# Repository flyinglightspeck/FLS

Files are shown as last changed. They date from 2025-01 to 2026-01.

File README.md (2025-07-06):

# FLS
Prototypes for flying light specks (FLSs).

This repository contains various designs for an FLS organized in directories named v*. Each design includes the 
electronic parts, 3D printable parts, instructions on assembling and configuring the FLS. 

The latest version is v5. Navigate to its directory for instructions, and assets.

# Writing Path for English Letters

### Table: Number of segments for writing paths of letters

| Letter | # Lit | # Dark | # Return | Total |
|---|---|---|---|---|
| A | 3 | 1 | 1 | 5 |
| B | 3 | 0 | 0 | 3 |
| C | 1 | 0 | 1 | 2 |
| D | 2 | 0 | 0 | 2 |
| E | 4 | 1 | 1 | 6 |
| F | 3 | 1 | 1 | 5 |
| G | 3 | 0 | 1 | 4 |
| H | 3 | 2 | 1 | 6 |
| I | 3 | 2 | 1 | 6 |
| J | 2 | 1 | 1 | 4 |
| K | 3 | 1 | 1 | 5 |
| L | 2 | 0 | 1 | 3 |
| M | 4 | 0 | 1 | 5 |
| N | 3 | 0 | 1 | 4 |
| O | 1 | 0 | 0 | 1 |
| P | 2 | 0 | 1 | 3 |
| Q | 2 | 1 | 1 | 4 |
| R | 3 | 1 | 1 | 5 |
| S | 1 | 0 | 1 | 2 |
| T | 2 | 1 | 1 | 4 |
| U | 2 | 0 | 1 | 3 |
| V | 2 | 0 | 1 | 3 |
| W | 4 | 0 | 1 | 5 |
| X | 2 | 1 | 1 | 4 |
| Y | 3 | 1 | 1 | 5 |
| Z | 3 | 0 | 1 | 4 |

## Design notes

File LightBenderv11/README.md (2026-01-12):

# ArduPilot Parameters
Load the ap_lightbender.params file or set the following parameters on the ArduPilot:

ARMING_CHECK 0

BATT_ARM_VOLT 7.5
BATT_CAPACITY 650
BATT_CRT_VOLT 7.2
BATT_LOW_VOLT 7.3

COMPASS_USE Disabled
COMPASS_USE2 Disabled
COMPASS_USE3 Disabled

EK3_MAG_CAL Use external yaw sensor
EK3_SRC1_POSZ GPS
EK3_SRC1_POSXY GPS
EK3_SRC1_VELZ GPS
EK3_SRC1_VELXY GPS
EK3_SRC1_YAW GPS

GPS_DELAY_MS 50
GPS_TYPE MAV

GYRO_FILTER 100

INS_LOG_BAT_MASK 1
INS_LOG_BAT_OPT 5
INS_HNTCH_ENABLE 1
INS_HNTCH_HMNCS 1 (set to 7 for three harmonics for tri-blade props)
INS_HNTCH_MODE 3 (ESC Telemetry)
INS_HNTCH_FREQ 400 (average hover RPM / 60)
INS_HNTCH_BW 100 (INS_HNTCH_FREQ / 4)
INS_HNTCH_REF 1
INS_HNTCH_OPTS 6 (Multi-source, Update at loop rate)
INS_HNTCH_FREQ 425 (average hover RPM / 60)
INS_HNTCH_BW 40 (at most INS_HNTCH_FREQ / 4)
INS_HNTCH_OPTS# ArduPilot Parameters
Load the ap_lightbender.params file or set the following parameters on the ArduPilot:

ARMING_CHECK 0

BATT_ARM_VOLT 7.5
BATT_CAPACITY 650
BATT_CRT_VOLT 7.2
BATT_LOW_VOLT 7.3

COMPASS_USE Disabled
COMPASS_USE2 Disabled
COMPASS_USE3 Disabled

EK3_MAG_CAL Use external yaw sensor
EK3_SRC1_POSZ GPS
EK3_SRC1_POSXY GPS
EK3_SRC1_VELZ GPS
EK3_SRC1_VELXY GPS
EK3_SRC1_YAW GPS

GPS_DELAY_MS 50
GPS_TYPE MAV

INS_GYRO_FILTER 162
INS_LOG_BAT_MASK 1
INS_LOG_BAT_OPT 5
INS_HNTCH_ENABLE 1
INS_HNTCH_HMNCS 1 (set to 7 for three harmonics for tri-blade props)
INS_HNTCH_MODE 3 (ESC Telemetry)
INS_HNTCH_FREQ 400 (average hover RPM / 60)
INS_HNTCH_BW 100 (INS_HNTCH_FREQ / 4)
INS_HNTCH_REF 1
INS_HNTCH_OPTS 6 (Multi-source, Update at loop rate)
INS_HNTCH_FREQ 375 (around average hover RPM / 60)
INS_HNTCH_BW 40 (start with INS_HNTCH_FREQ / 4 then narrow down)
INS_HNTCH_OPTS 6 (Multi-source, Update at loop rate)

LAND_SPEED 30

LOG_BITMASK 2504447 (Check all except for mission commands, optical flow, camera, raw imu, and video stabilization)

OSD_CELL_COUNT 2

RPM1_TYPE 5 (ESC Telemetry Motors Bitmask)

RPM1_ESC_MASK 15 (Channels 1 - 4)
SERVO_BLH_BDMASK 15 (Channels 1 - 4)
SERVO_BLH_POLES 14 (If using another motor count the number of magnets inside the rotor and put in the correct number)
SERVO_DSHOT_ESC 1 (BLHeli32/Kiss/AM32)

SERIAL1_BAUD 921600

VISO_TYPE MAVLink

LAND_SPEED 30

LOG_BITMASK 2504447 (Check all except for mission commands, optical flow, camera, raw imu, and video stabilization)

OSD_CELL_COUNT 2

RPM1_TYPE 5 (ESC Telemetry Motors Bitmask)

RPM1_ESC_MASK 15 (Channels 1 - 4)
SERVO_BLH_BDMASK 15 (Channels 1 - 4)
SERVO_BLH_POLES 14 (If using another motor count the number of magnets inside the rotor and put in the correct number)
SERVO_DSHOT_ESC 1 (BLHeli32/Kiss/AM32)

SERIAL1_BAUD 921600

VISO_TYPE MAVLink

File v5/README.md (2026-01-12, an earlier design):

# 60mm FLS with MicoAir H743v2 AIO

## V5.3.60

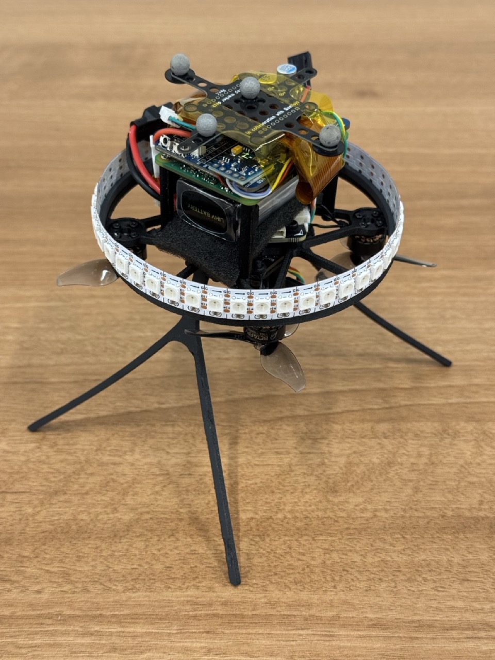
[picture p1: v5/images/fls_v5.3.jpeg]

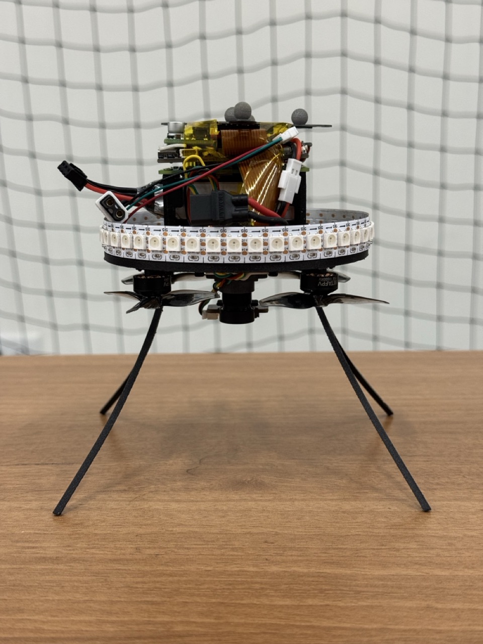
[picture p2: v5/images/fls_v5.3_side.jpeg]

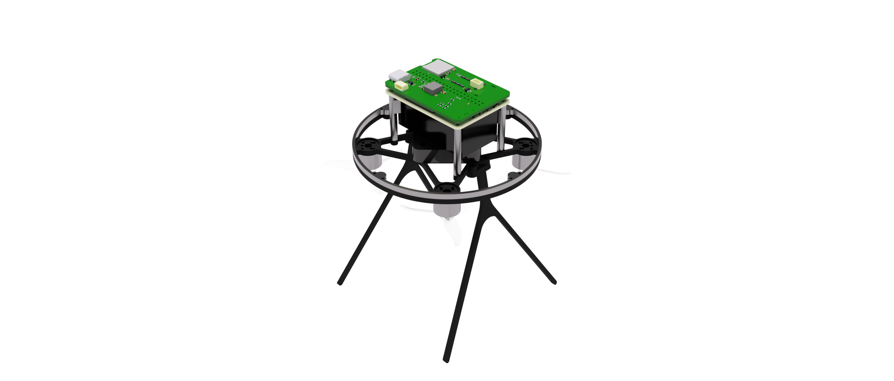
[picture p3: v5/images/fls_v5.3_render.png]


3D model: `v5/3d/FLS_v5.3.60.f3z`.

## Parts

- [MicoAir H743v2 AIO 45A](https://store.micoair.com/product/micoair743v2-aio-45a/)
- [6000KV Motors](https://flywoo.net/products/robo-1303-6000kv-2-4s-fpv-motor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)
- [Raspberry Pi CM5](https://www.raspberrypi.com/products/compute-module-5/?variant=cm5-104032)
- [Raspberry Pi Camera Module 3 Wide NoIR](https://www.pishop.us/product/raspberry-pi-camera-module-3-wide-noir/)
- [Nano Base Board (A) for Raspberry Pi Compute Module 5](https://www.waveshare.com/cm5-nano-a.htm), also
  on [Amazon](https://a.co/d/2dPvVRj)
- [Pololu 5V, 5A Step-Down Voltage Regulator D24V50F5 to power Raspberry Pi](https://www.pololu.com/product/2851)
- [Molex connectors](https://a.co/d/1OW0Edu)
- [2S 650mAh 120C Lipo Battery](https://a.co/d/c1O34hy)
- [Raspberry Pi Camera Module 3 Wide NoIR](https://www.raspberrypi.com/products/camera-module-3/?variant=camera-module-3-noir-wide)
- [Raspberry Pi Camera Module 3 Sensor Cable Extension](https://www.arducam.com/200mm-sensor-extension-cable-for-raspberry-pi-v2-v3-support-working-on-raspberry-pi-and-jetson.html)
- [MicoAir MTF-02 Flow and Range Sensor](https://robofusion.net/products/micoair-optical-flow-lidar-sensor-mtf-02-compatible-with-ardupilot-px4-inav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)
- 2-inch Propellers (Any of the bellow options):
    - [Gemfan D51 Ducted 4-Blade](https://www.getfpv.com/gemfan-d51-ducted-durable-4-blade-51mm-cinewhoop-propeller-set-of-8.html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)
    - [Gemfan Hurricane 2023S 3-Blade](https://www.getfpv.com/propellers/micro-quad-propellers/gemfan-hurricane-2023s-3-blade-propeller-set-of-8.html)
    - [HQProp T2X2X3 3-Blade](https://www.getfpv.com/propellers/micro-quad-propellers/hqprop-t2x2x3-3-blade-propeller-set-of-4.html)

You can also use CM4 instead of CM5 (CM4 is slower than CM5):

- [Raspberry Pi CM4](https://www.raspberrypi.com/products/compute-module-4/?variant=raspberry-pi-cm4104032)
- [Nano Base Board (A) for Raspberry Pi Compute Module 4](https://www.waveshare.com/cm4-nano-a.htm), also
  on [Amazon](https://a.co/d/gfsPdik)

## Assembly

### 3D Print

We used Bambu X1 Carbon printer to print the following parts using Bambu PA6-CF filament. The models are available
in the `3d` directory. All the items you need to print is inside the Bambu project named `print_plates.3mf` open 
this file using Bambu studio and print the plates.

| name | qty |
|---|-----|
| frame_v4 | 1 |
| pi_holder_v2_a | 2 |
| pi_holder_v2_b | 1 |
| pi_holder_v2_b_slit | 1 |
| landing_gear_v3 | 2 |
| cam_holder_l | 1 |
| cam_holder_r | 1 |
| sensor_holder | 1 |

Important Notes:

- Dry the filament before printing for the best result.
- Use smooth PEI / high temp plate.
- Clean the oil, fingerprints, and printing waste from the plate before printing.
- For printing Plate 1 use `0.2mm strength` profile, add 5mm of outer brim, and use `concentric` top and bottom
  surface pattern.
- For Plates 2 and 3 use `0.16mm high quality` profile. Enable 5mm outer brim for Plate 2. Enable manual 
  support for Plate 3.
- After printing completes do not remove the part. Wait util the plate temperature drops to around 40 degrees
  Celsius. Otherwise, the printed part may bend permanently.
- Store the filament in a sealed zip bag after use.

### Installation

1. Install the motors to the frame using the black M2 screws that are included in their package. You can install
   them on either side of the frame.
2. Install the rubber grommets on the FC in a way that the taller part is on the side that the USB port is.
3. Solder the battery cable, Molex cable and the capacitor to the FC battery pads.
4. Install the FC on the frame. Note the orientation of the FC. The white arrow on the top of the FC shows the front
   direction.

5. Solder the wires of the motors to the motor pads of the FC, the order of the wires does not matter.
6. Install Pi holders on the frame.
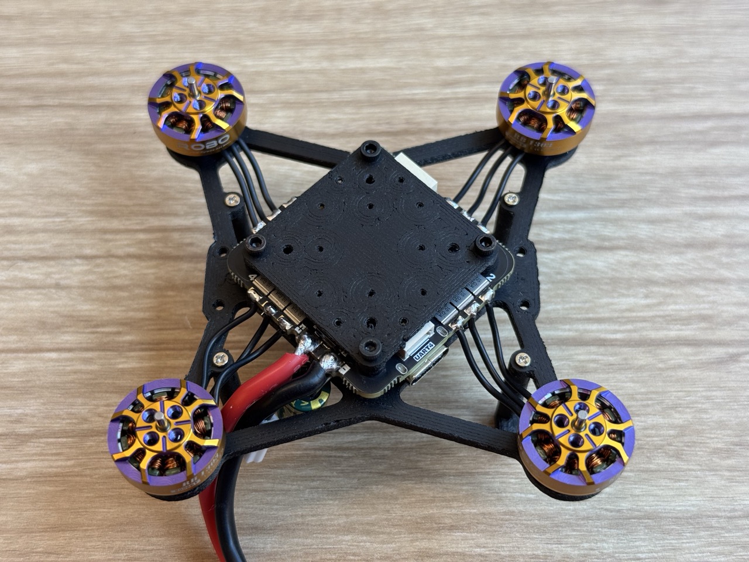
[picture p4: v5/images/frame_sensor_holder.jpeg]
   
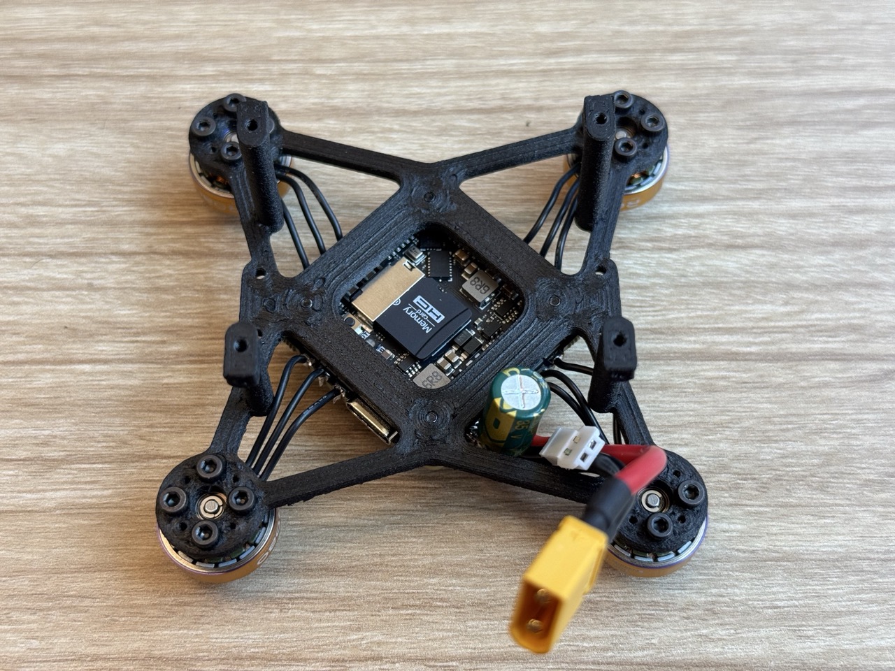
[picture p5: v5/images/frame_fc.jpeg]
   
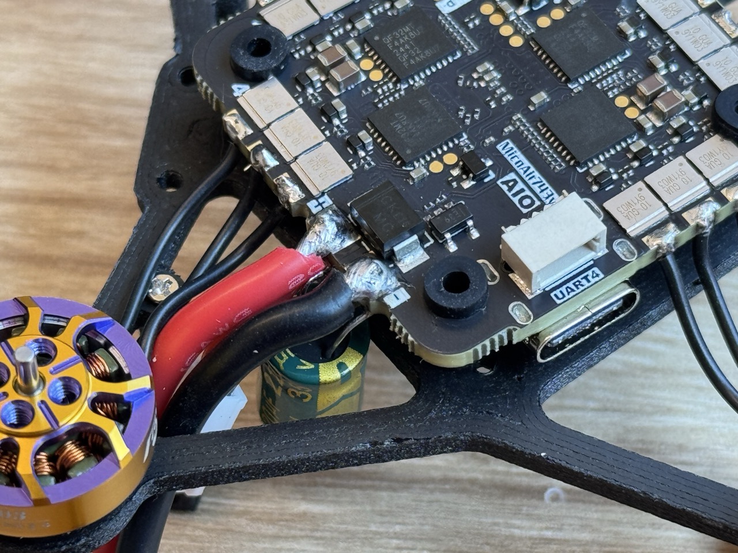
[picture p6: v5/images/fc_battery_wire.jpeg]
   

7. Install Pi CM5 on the frame, note the orientation.
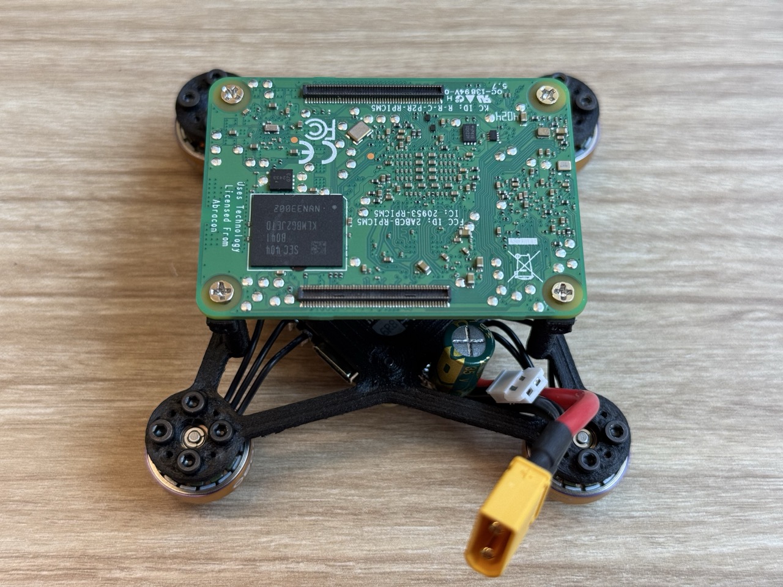
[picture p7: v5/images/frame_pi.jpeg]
   

8. Solder a Molex cable, power adapter, and TX/RX cables on the NANO baseboard.
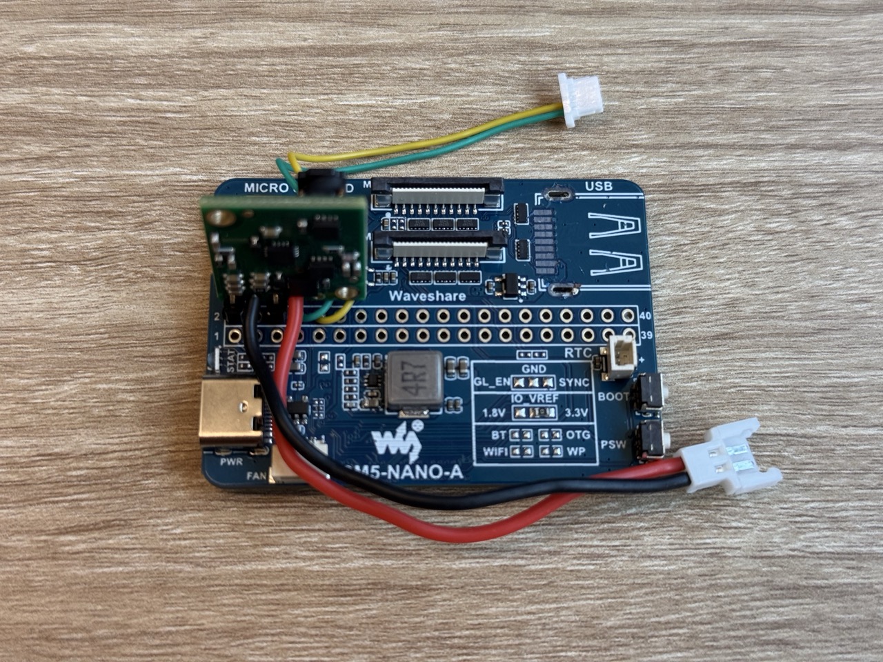
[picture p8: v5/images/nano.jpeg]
   
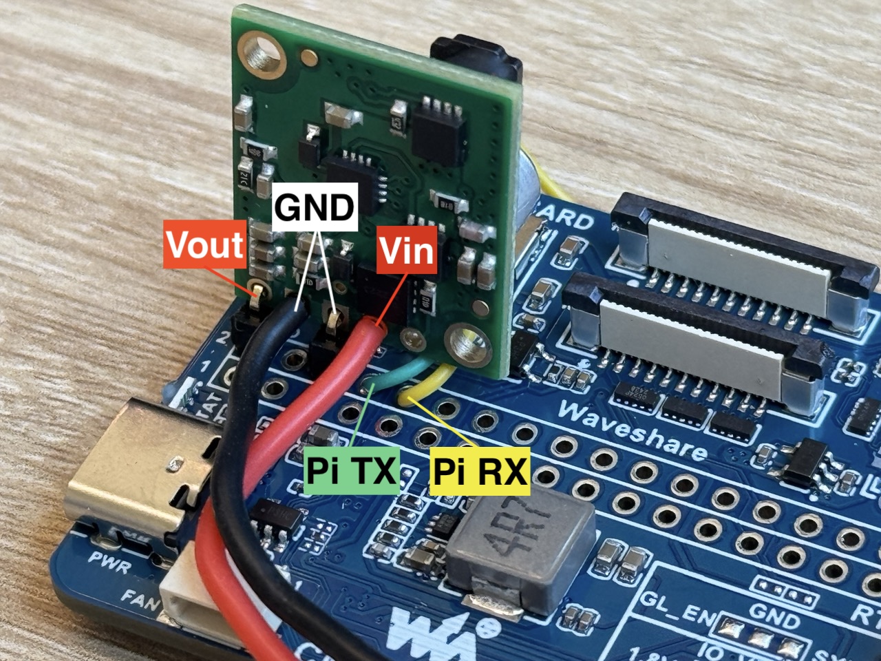
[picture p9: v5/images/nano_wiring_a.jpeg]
   
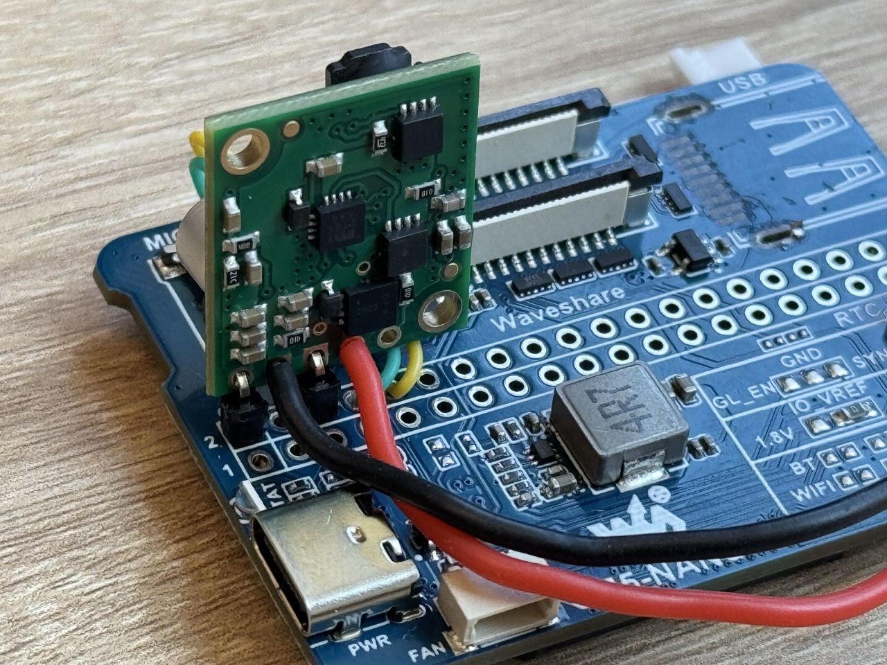
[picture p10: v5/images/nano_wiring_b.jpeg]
   

We used the 4-pin connector that comes with the FC as the TX/RX cable. We removed the black and green wires as we
are not using them. This connector connects the FC TX to Pi RX (yellow) and FC RX to Pi TX (green).

9. Install the NANO board on the Pi CM5.
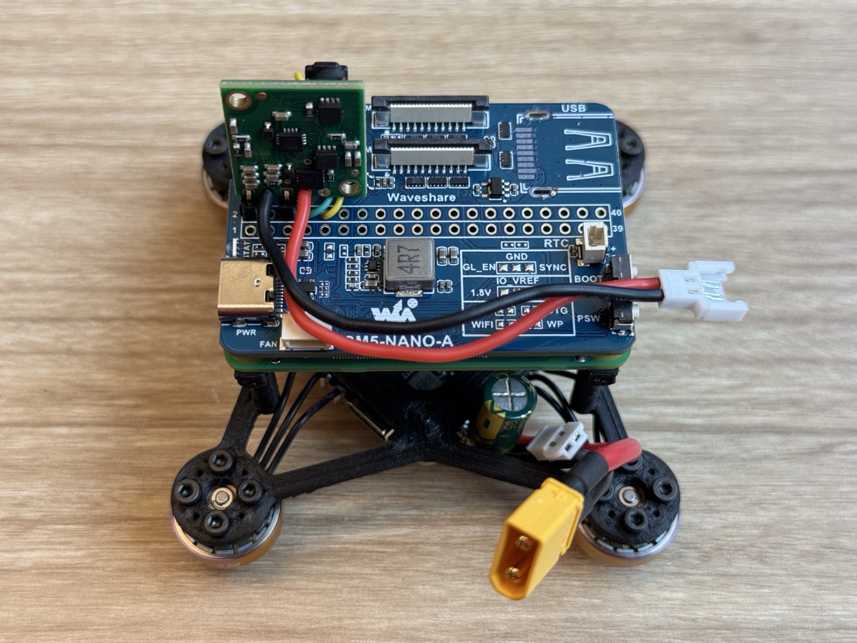
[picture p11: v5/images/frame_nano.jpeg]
   
10. Connect the TX/RX and power connector to the FC.
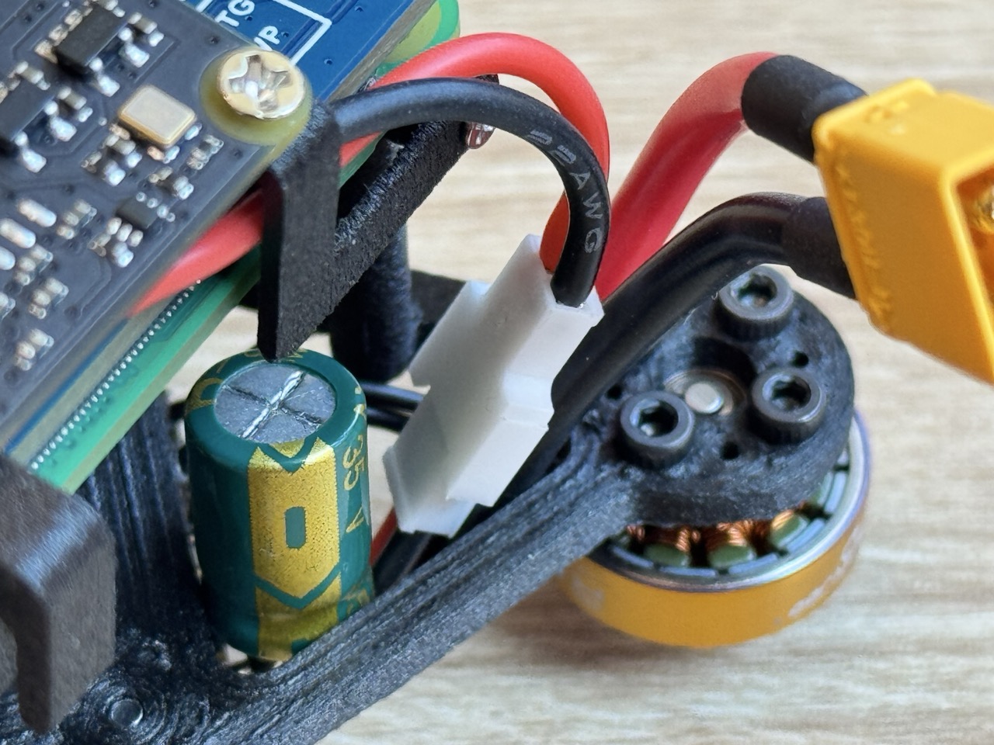
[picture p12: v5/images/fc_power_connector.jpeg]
    
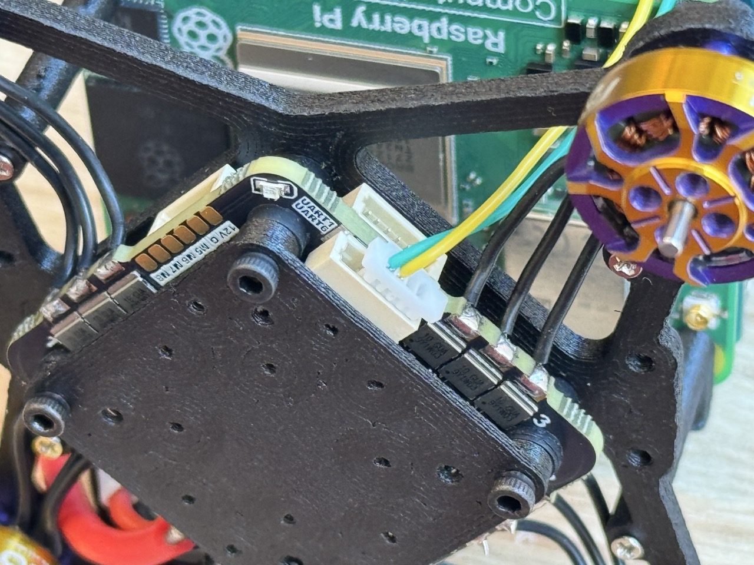
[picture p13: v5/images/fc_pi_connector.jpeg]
    

11. Remove the camera sensor from the Raspberry Pi Camera board and install the camera holders to it using 4 M2x3
    screws.
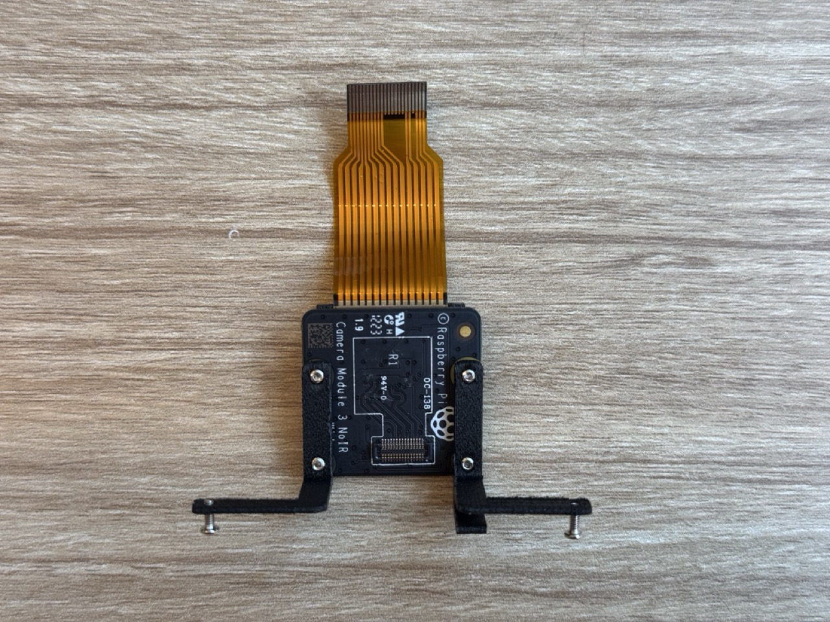
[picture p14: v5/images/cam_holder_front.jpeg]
    
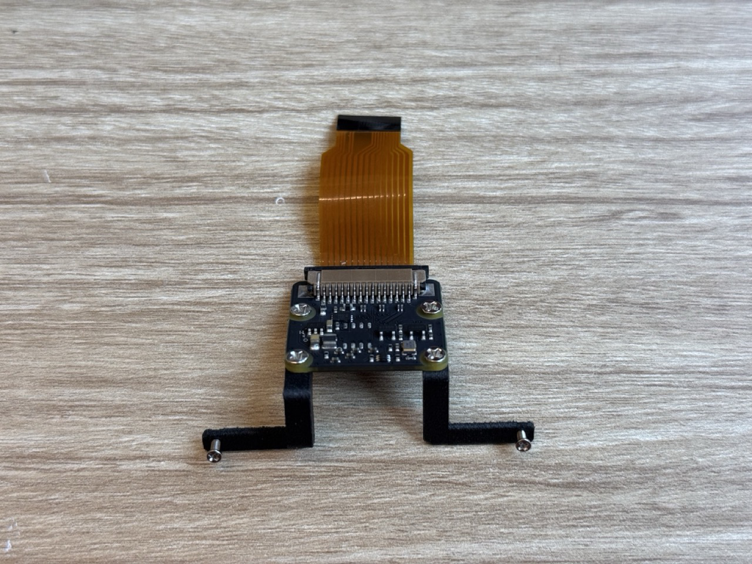
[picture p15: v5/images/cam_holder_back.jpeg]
    

12. Install the camera holders on the Pi holders using 2 M1.4x4 screws.
13. Connect the camera board connector to the MIPI0 connector of the NANO board.
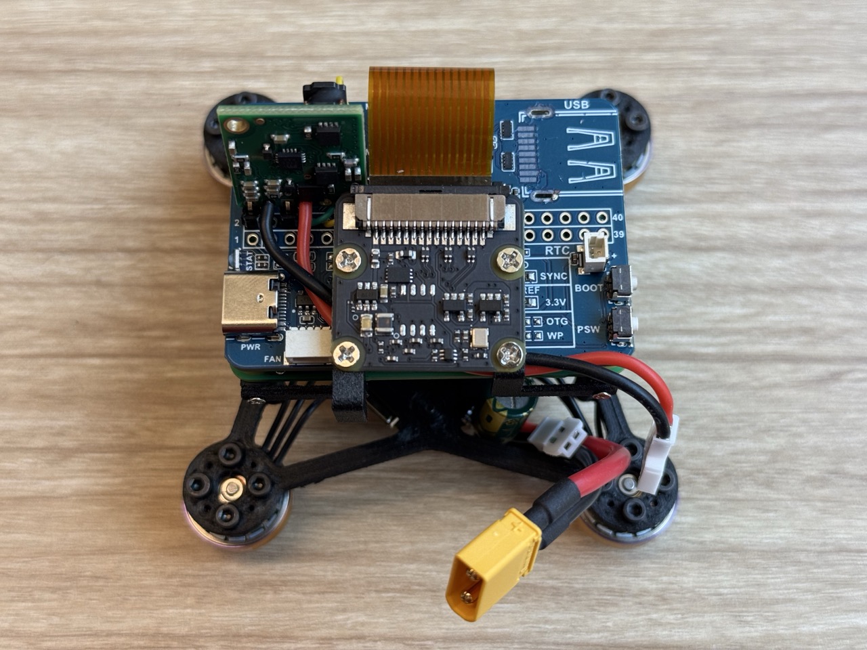
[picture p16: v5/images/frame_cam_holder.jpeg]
    

14. Do not install propellers until you have conducted the initial tests.
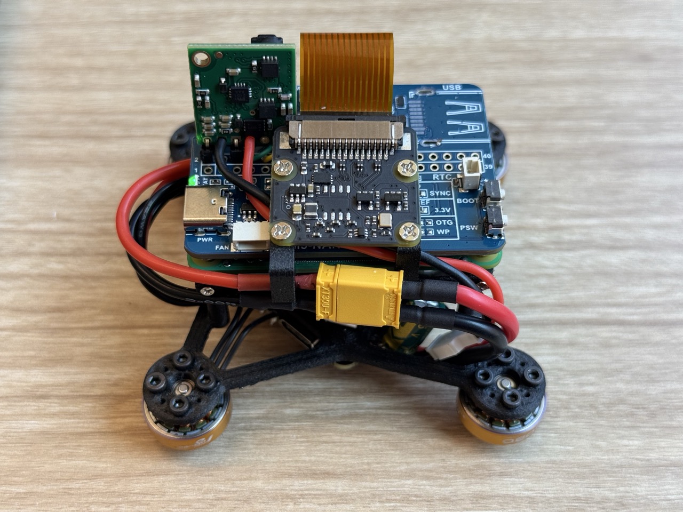
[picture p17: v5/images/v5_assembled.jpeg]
    

## Configure Raspberry Pi CM4/CM5

Using and configuring Raspberry Pi Compute Module requires a baseboard, here I used WaveShare Nano Base Board (A).
The instructions are the same for CM5 except noted otherwise.
Use the compatible baseboard based on the raspberry pi model as its camera interface is not cross-compatible between
CM4 and CM5.

### Install OS

Install Raspberry Pi OS 64-bit
following [this guide](https://www.raspberrypi.com/documentation/computers/compute-module.html#flash-compute-module-emmc).
Configure SSH and WiFi when writing the OS using Raspberry Pi Imager.
After installing the OS, ssh to the RPi and update the packages:

```
sudo apt update && sudo apt upgrade -y
```

### Camera Configuration

```
sudo vim /boot/firmware/config.txt
```

Add the following line under [cm4] or [cm5]:

for Raspberry Pi camera module 3:
```
dtoverlay=imx708,cam0
```

For ov9281 global shutter camera:
```
dtoverlay=ov9281,cam0
```

### Enable UART

1. Open config file:

```commandline
sudo vim /boot/firmware/config.txt
```

2. Paste this at the end

```
enable_uart=1
dtoverlay=disable-bt,uart0,ctsrts
```

3. Open cmdline file:

```commandline
sudo vim /boot/firmware/cmdline.txt
```

3. Remove this phrase `console=serial0,115200` if present.
2. Reboot Raspberry Pi:

```commandline
sudo reboot
```

### Create Python Environment

```
python3 -m venv env
```

To proceed with installing Python packages activate the env:

```
source env/bin/activate
```

Also, add the above to the `.bashrc` file to always activate venv.

### Install Mavlink-Router

Install [mavlink-router](https://github.com/mavlink-router/mavlink-router?tab=readme-ov-file).

```commandline
git clone https://github.com/mavlink-router/mavlink-router.git
cd mavlink-router
git submodule update --init --recursive
sudo apt install git meson ninja-build pkg-config gcc g++ systemd
meson setup build .
ninja -C build
sudo ninja -C build install
```

We will use this to connect to the drone using QGroundStation over WiFi and through Pi.

When the Pi and ground computer are connected to the same network run this on the Pi:

```commandline
mavlink-routerd -e 192.168.1.230:14550 /dev/ttyAMA0:921600
```

Then open QGroundControl and wait until it connects to the FC.

In the first stages of build process we need to connect to the drone wirelessly to configure and fly it using
joystick. Hence, it's convenient to start mavlink-routerd automatically on Pi start up.

1. Create a service file:

```commandline
sudo vim /etc/systemd/system/mavlink-router.service
```

2. Paste this:
   Replace `192.168.8.197` with the IP address of your ground computer.

```
[Unit]
Description=MAVLink Router
After=network.target

[Service]
ExecStart=/usr/bin/mavlink-routerd -e 192.168.8.197:14550 /dev/ttyAMA0:57600
Restart=on-failure
User=pi  # or whatever user you use

[Install]
WantedBy=multi-user.target
```

3. Reload systemd to pick up the new service:

```commandline
sudo systemctl daemon-reexec
sudo systemctl daemon-reload
```

4. Enable it to run at boot:

```commandline
sudo systemctl enable mavlink-router.service
```

5. Start it now (optional):

```commandline
sudo systemctl start mavlink-router.service
```

6. Confirm it works:

```commandline
sudo systemctl status mavlink-router.service
```

If you want to change the command later:

```commandline
sudo vim /etc/systemd/system/mavlink-router.service
sudo systemctl daemon-reload
sudo systemctl restart mavlink-router.service
```

If you no longer need it in the future:

```commandline
sudo systemctl disable mavlink-router.service
```

### Configure LED Strip

```
pip install rpi_ws281x adafruit-circuitpython-neopixel
pip install --force-reinstall adafruit-blinka
pip install adafruit-circuitpython-neopixel-spi lgpio
```

Enable SPI:
```
sudo vim /boot/firmware/config.txt
```
Paste this:
```
dtparam=spi=on
```

### Offboard Controller

Install mocap lib requirements:
```commandline
sudo apt install libboost-system-dev libboost-thread-dev libeigen3-dev ninja-build
```

Clone this repository on RPI and follow the help from the controller.py to fly the FLS.

```
cd ~
git clone https://github.com/flslab/fls-ap-offboard-controller.git
cd fls-ap-offboard-controller
mkdir logs
pip install -r requirements.txt
```

lib motioncapture is the one from https://github.com/IMRCLab/libmotioncapture.

### Servo
```commandline
pip install gpiozero lgpio pigpio
```
Add to `/boot/firmware/config.txt`
```
dtoverlay=pwm
```

### Marker Localization

Install dependencies:

```
sudo apt install -y cmake libopencv-dev nlohmann-json3-dev libeigen3-dev libcamera-dev
```

```
cd ~
git clone https://github.com/flslab/fls-marker-localization.git
```

Build:

```
cd fls-marker-localization
mkdir build
cd build
mkdir logs
cmake ..
make -j4
```

Copy Config:

```
cp ../src/gs_camera_config.json camera_config.json
```

Run for 10 seconds to test:

```
./eye -t 10
```

## Configure ArduPilot

### Install Ground Station Software

Install QGroundControl, QGC for short, from here.

[Mission Planner](https://ardupilot.org/planner/docs/mission-planner-installation.html) can also be used if on Windows.

### Install Firmware

We used ArduPilot 4.5.7 for this built. If your FC has another firmware installed by default, like BetaFlight of PX4,
first refer to Install Bootloader and download the bootloader on the FC. This information is usually marked on the
packaging box of the FC.

1. Download `4.5.7/MicoAir743v2_ArduCopter-4.5.7.apj`
   from [here](https://github.com/micoair/MicoAir743v2/tree/main/Firmware/Ardupilot).
2. Open QGC and go to Firmware tab by clicking on the Q icon and Vehicle Configuration in the top left
   corner.
3. When in the firmware tab, connect the FC to your computer using a USB type C cable.
4. Choose ArduPilot and select Custom firmware file... from the dropdown menu.
5. Hit Ok then browse and choose the `.apj` file you downloaded.
6. Wait until installation completes. Disconnect and connect and the board again.

You can load the parameters from `fls_v5.3.params` instead on setting them step by step using QGroundControl or Mission 
Planner. Review all the changes before writing the values to check if they match your setup.

### Choose Frame Type

In the Frame tab choose Quad and set the type to X.

### Sensor Calibration

Complete accelerometer calibration and level horizon from the Sensors tab.

### Battery Configuration

1. Go to the Power tab and set the capacity of battery to 650mAh.
2. Go to the Parameters tab and set `BATT_LOW_VOLT` to 6.6. This is the minimum voltage for 2S battery. Use 10.5 for
   3S or 14.0 for 4S.

### Logging
```
LOG_BITMASK 2506751 (Check all except for camera, raw imu, and video stabilization)
INS_LOG_BAT_MASK 1
INS_LOG_BAT_OPT 5
```

### Disable Arming Checks

Go to the Parameters and uncheck all items from `ARMING_CHECK`.

### Make Sure Serial Port is Set Correctly

We are using UART1 for FC - Pi communications. The default settings works without modifications. Make sure to change
the baud rate in the ArduPilot parameters and scripts/commands if you are not using the default.
```
SERIAL1_PROTOCOL 2 (MAVLink2)
SERIAL1_BAUD 921600
```

### Tune the PID

1. Go to the Tuning tab.
2. Enable the advanced mode.
3. Set the gains for the Rate controller according to this table for each axis:

| Axis  | P | I | D |
|---|---|---|---|
| Roll  | 0.04 | 0.05  | 0.003 |
| Pitch | 0.04 | 0.05  | 0.003 |
| Yaw | 0.15 | 0.018 | 0 |

### Enable Harmonic Notch Filter

In ArduPilot, a harmonic notch filter is a type of signal processing filter used to attenuate specific frequencies,
typically those related to motor noise or vibrations. It's designed to remove these interfering frequencies from gyro
data, improving the accuracy and reliability of the flight control system.

1. Go to Parameters tab and set `INS_HNTCH_ENABLE` to 1.
2. Reboot using the option in the Tools menu.
3. Set the following parameters:

```
INS_HNTCH_ENABLE 1
INS_HNTCH_HMNCS 1 (set to 7 for three harmonics for tri-blade props)
INS_HNTCH_MODE 3 (ESC Telemetry)
INS_HNTCH_FREQ 400 (average hover RPM / 60)
INS_HNTCH_BW 100 (INS_HNTCH_FREQ / 4)
INS_HNTCH_REF 1
INS_HNTCH_OPTS 6 (Multi-source, Update at loop rate)
INS_ACCEL_FILTER 20
INS_GYRO_FILTER 100
```

### Bi-Directional DShot for RPM
```
RPM1_TYPE 5 (ESC Telemetry Motors Bitmask)
```
Reboot.
```
RPM1_ESC_MASK 15 (Channels 1 - 4)
SERVO_BLH_BDMASK 15 (Channels 1 - 4)
SERVO_BLH_POLES 12 (If using another motor count the number of magnets inside the rotor and put in the correct nomber)
SERVO_DSHOT_ESC 1 (BLHeli32/Kiss/AM32)
```

### Motors
Set `MOT_PWM_TYPE` to DShot300.

1. Disconnect FC from QGC.
2. Connect battery to the drone and wait until it stops buzzing.
3. Connect FC to QGC using USB.
4. In QGC, go to Motors tab.
5. Enable motor sliders.
6. Set the spin percentage to 5-10% by dragging the slider.
7. Spin the motors in turn by clicking on A, B, C, and D buttons.
8. Check the rotation direction of the motors.

If you need to change the direction of motors follow these steps:

1. Set SERVO_BLH_AUTO to 1 (enabled) and set SERVO_BLH_MASK to 15 (enable Channel1-4).
   **Note:** you should restore these two parameters to their default values after the ESC 
   configuration, otherwise the ESC cannot be worked normally.
2. Reboot the drone.
3. Go to [esc-configurator.com](https://esc-configurator.com) or [am32 configurator](https://am32.ca/configurator).
4. Click on Open Port Selection in the upper right corner, select "MicoAir743", and then click on Connect.
5. Click on Read Settings in the bottom right corner to read the configuration of the ESCs.
6. Change the motor rotation direction (Normal or Reverse) in the Motor Direction option for each ESC. The number 
   in front of ESC is the same as the numbers printed on the FC board.
7. Click Write Settings after configuration.
8. Disconnect.
9. Test the directions again to ensure they are correct.

## Initial Flight Test

After configuring ArduPilot, you are ready to conduct your first flight using a joystick.

1. Connect the joystick to your ground computer.
2. Open QGC.
2. Configure the joystick and assign buttons if needed in the Joystick tab of QGC.
TBD

## Install Compass

## Install MTF-02 (Flow and Range Finder Sensor)
1. Set the following parameters in QGC:
```
SERIAL4_BAUD 115
SERIAL4_OPTIONS 1024 (Don’t forward mavlink to/from)
SERIAL4_PROTOCOL 1 (MAVLink1)
FLOW_TYPE 5 (MAVLink)
RNGFND1_TYPE 10 (MAVLink)
```
2. Reboot FC to refresh the list of parameters.
3. Set the following parameters.
```
RNGFND1_MAX_CM 800
RNGFND1_MIN_CM 1
RNGFND1_ORIENT 25 (Down)
```

```
AHRS_EKF_TYPE 3
EK3_SRC_OPTIONS 0
EK3_SRC1_POSXY 0 (None)
EK3_SRC1_POSZ 2 (RangeFinder)
EK3_SRC1_VELXY 5 (OpticalFlow)
EK3_SRC1_VELZ 0 (None)
EK3_SRC1_YAW 1 (Compass)
EK3_GPS_CHECK 0
EK3_HGT_DELAY 0
```

```
AHRS_GPS_USE 0 (Disabled)
```

5. Connect the flow sensor using its connector the UART4 pin on the FC.

## Localization Settings
```
VISO_TYPE 1 (MAVLink)
VISO_POSE_M_NSE 0.1
```

### Flow sensor and range finder
```
EK3_SRC1_POSXY 0 (ExternalNav)
EK3_SRC1_POSZ 2 (RangeFinder)
EK3_SRC1_VELXY 5 (OpticalFlow)
```

### Camera and range finder
```
EK3_SRC1_POSXY 6 (ExternalNav)
EK3_SRC1_POSZ 2 (RangeFinder)
EK3_SRC1_VELXY 0 (None)
EK3_FLOW_USE None
```

### Vicon
```
EK3_SRC1_POSXY 6 (ExternalNav)
EK3_SRC1_POSZ 6 (ExternalNav)
EK3_SRC1_VELXY 0 (None)
EK3_FLOW_USE None
```

## Simulation

Download ArduPilot repository and set it up, then run the following command:

```
 ./Tools/autotest/sim_vehicle.py -v ArduCopter
```

run the offboard controller using the `--sim` argument to connect to the simulator.

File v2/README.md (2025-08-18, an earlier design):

# FLS with Crazyflie Bolt 

## Parts
- [Crazyflie Bolt 1.1](https://www.bitcraze.io/products/crazyflie-bolt-1-1/)
- [6000KV Motors](https://www.getfpv.com/motors/micro-quad-motors/flywoo-robo-1303-motor-6000kv.html)
- [ESC](https://www.getfpv.com/dys-xsc-20a-blheli-s-esc.html)
- [Raspberry Pi CM5](https://www.raspberrypi.com/products/compute-module-5/?variant=cm5-104032)
- [Raspberry Pi Camera Module 3 Wide NoIR](https://www.pishop.us/product/raspberry-pi-camera-module-3-wide-noir/)
- [Nano Base Board (A) for Raspberry Pi Compute Module 5](https://www.waveshare.com/cm5-nano-a.htm), also on [amazon](https://a.co/d/2dPvVRj)
- [Step down DC-DC 5V 5A voltage regulator to power Raspberry Pi](https://a.co/d/0ukGvxB)
- [Micro USB Male Port](https://a.co/d/9cJU9Qm)
- [Molex connectors](https://a.co/d/1OW0Edu)
- [Lipo Battery 850mAh 80C 11.1V 3S](https://a.co/d/hYqlLo6)

You can also use CM4 instead of CM5:
- [Raspberry Pi CM4](https://a.co/d/buHcjwu)
- [Nano Base Board (A) for Raspberry Pi Compute Module 4](https://www.waveshare.com/cm4-nano-a.htm), also on [amazon](https://a.co/d/gfsPdik)

## Configure Raspberry Pi CM4
Using and configuring Raspberry Pi Compute Module requires a baseboard, here I used WaveShare Nano Base Board (A).
The instructions are the same for CM5 except noted otherwise.
Use the compatible baseboard based on the raspberry pi model. The camera interface is not cross-compatible between CM4 and CM5. 

### Install OS
Install Raspberry Pi OS 64-bit following [this guide](https://www.raspberrypi.com/documentation/computers/compute-module.html#flash-compute-module-emmc).
Configure SSH and WiFi when writing the OS using Raspberry Pi Imager.
After installing the OS, ssh to the RPi and update the packages:
```
sudo apt update && sudo apt upgrade -y
```

### Create Python Environment
```
python3 -m venv env
```

To proceed with installing Python packages activate the env:
```
source env/bin/activate
```

### Configure LED Strip
```
pip install rpi_ws281x adafruit-circuitpython-neopixel
pip install --force-reinstall adafruit-blinka
```

### USB Configuration
Ensure USB is enabled by adding the following to the RPI `sudo`:
```
dtoverlay=dwc2,dr_mode=host
```

Connect RPi to CFBolt using usb cable.
```
$ lsusb
Bus 005 Device 003: ID 0483:5740 STMicroelectronics Virtual COM Port
Bus 005 Device 001: ID 1d6b:0002 Linux Foundation 2.0 root hub
```

Create a udev rule so that the correct permissions are applied automatically every time the device is connected.
```
sudo vim /etc/udev/rules.d/99-crazyflie.rules
```
Paste the following and save:
```
SUBSYSTEM=="usb", ATTR{idVendor}=="0483", ATTR{idProduct}=="5740", MODE="0666"
```
Apply the new rules:
```
sudo udevadm control --reload-rules
sudo udevadm trigger
```
Disconnect and reconnect the device. The new permissions should now apply automatically.

To verify, after reconnecting the Crazyflie, check the permissions again:
```
ls -l /dev/bus/usb/005/003
```
It should show:
```
crw-rw-rw- 1 root root ...
```

### Offboard Controller
Install dependencies:
```
git clone https://github.com/bitcraze/crazyflie-lib-python.git
cd crazyflie-lib-python
pip install -e .
pip install pyserial
```
```
git clone https://github.com/flslab/fls-cf-offboard-controller.git
```

### Camera Configuration
```
sudo vim /boot/firmware/config.txt
```
Add the following line under [cm4] or [cm5]:
```
dtoverlay=imx708,cam0
```

### Marker Localization
Install dependencies:
```
sudo apt install -y cmake libopencv-dev nlohmann-json3-dev libeigen3-dev libcamera-dev
```
```
git clone https://github.com/flslab/fls-marker-localization.git
```

Build:
```
cd fls-marker-localization
mkdir build
cd build
cmake ..
make -j4
```

Copy Config:
```
cp ../src/camera_config.json .
```

Run for 10 seconds to test:
```
./eye -t 10
```

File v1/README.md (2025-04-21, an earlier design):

# FLS
A prototype for flying light specks

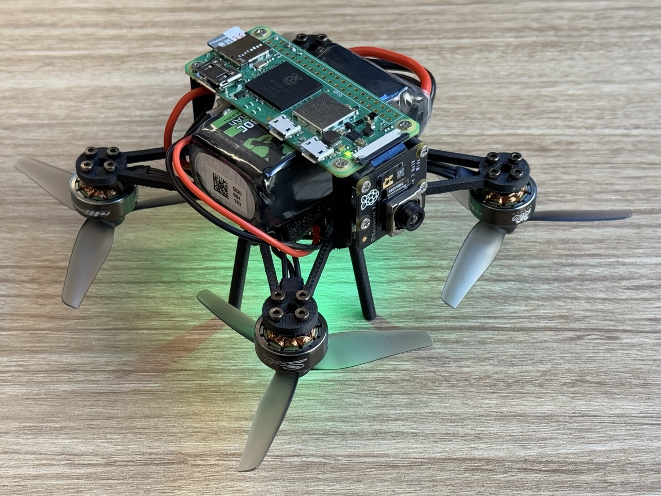
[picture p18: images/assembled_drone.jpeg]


For BetaFlight or iNav see [here](betaflight_inav).

## Steps to reproduce
1. Flash the firmware to the flight controller
2. Connect the motors and other connections
3. Test the direction of rotation for each motor
4. Assemble the parts on the frame
5. Configure the flight controller
6. Configure Raspberry Pi

## List of parts
1. [iFlight BLITZ Whoop F7 AIO flight controller](https://shop.iflight.com/BLITZ-Whoop-F7-AIO-Pro1927)
2. [1404 Plus 6000kv motors](https://www.myfpvstore.com/motors/rcinpower-smoox-1404-plus-whoop-motor-gunmetal-blue-6000kv/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)
3. [HQ Prop T3X2X3 Tri-Blade 3" Prop 4 Pack 1.5mm Shaft](https://www.racedayquads.com/products/hq-prop-t3x2x3-1-5mm-shaft-tri-blade-3-prop-4-pack-choose-color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)
4. [Raspberry Pi Zero 2 W + SD card with Raspberry OS](https://www.pishop.us/product/raspberry-pi-zero-2-w/?src=raspberrypi)
5. [Raspberry Pi Camera Module 3 Wide NoIR](https://www.pishop.us/product/raspberry-pi-camera-module-3-wide-noir/)
6. [Lipo Battery 850mAh 80C 11.1V 3S](https://a.co/d/hYqlLo6)
7. [4pcs XT30 XT-30 to XT60 XT-60 Male Female RC Connector Adapter](https://a.co/d/1hygTM4)
8. [M2 screws](https://a.co/d/6PfypLR)
9. [Enameled copper wire](https://a.co/d/gU8BKby)
10. [Charger](https://a.co/d/1dvDkIm)
11. [Molex connectors](https://a.co/d/1OW0Edu)

## Install ArduPilot on the flight controller
This prototype uses iFlight BLITZ Whoop F7 AIO which is a all-in-one flight controller with built-in ESC.
The default firmware on the BLITZ Whoop F7 AIO is BetaFlight. Here is how to replace it with ArduPilot.

Custom build ArduPilot with optical flow support:
with ek3 optical flow fusion: https://custom.ardupilot.org/builds/copter:BlitzF745AIO:450ffd1520a64c00f0bd4492a479e43c75e170d7:e71419b2971fff2e338a09a9cc65b3b2/
https://custom.ardupilot.org/builds/copter:BlitzF745AIO:bfa40f76d8808a8c51c63293a869967a488f229b:e2ae6074c5bcf21c45d9cb0401fd5167/
```
default firmware (December 2024):
# version
# Betaflight / STM32F745 (S745) 4.5.1 Jul 27 2024 / 07:57:01 (77d01ba3b) MSP API: 1.46
# config rev: 11c7dec
# board: manufacturer_id: IFRC, board_name: IFLIGHT_BLITZ_F7_AIO
```

1. Install [STM32CubeProgrammer](https://www.st.com/en/development-tools/stm32cubeprog.html).
2. Install a compatible ground station software from [here](https://ardupilot.org/plane/docs/common-install-gcs.html) (QGroundControl for mac).
3. Open [this link](https://firmware.ardupilot.org/), go to Copter > stable > BlitzF745AIO and download `arducopter_with_bl.hex`.
4. Follow instructions (here)[https://ardupilot.org/plane/docs/common-loading-firmware-onto-chibios-only-boards.html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] to install the firmware using STM32 Cube Programmer.

## Connections
1. Measure and cut the motor's wires (I kept around 32 mm).
2. Solder the wires to the motor pins on the flight controller board. For now the order of the wires doesn't matter we'll test the rotation direction in the next step and reorder them if necessary. You can use the pins on either side of the board. I used the upper part (where the USB port is present)
3. Solder the XT30 wire to the power pins (red to the + and black to -). I used the upper side pins.
4. Solder the capacitor the power pins, pay attention to the - and + pins. I connected the capacitor to the bottom side.
   
5. Connect a wire with male Molex connector to the 5V and GND pins of the flight controller (red to 5V and black to the GND).
6. Connect a wire with female Molex connector corresponding pins of Raspberry Pi.
7. See [this guide](https://www.raspberrypi.com/documentation/computers/raspberry-pi.html#gpio) for Raspberry Pi pins and [this](https://ardupilot.org/plane/docs/common-iflight-blitzf7AIO.html#pinout) for the flight controller pins.
8. Cut two pieces of 10-cm enameled copper wire and solder them to the T4 and R4 pins on the flight controller board. This is for the communication of the flight controller and Raspberry Pi. SERIAL4 and SERIAL7 pins are free for custom applications. See [here](https://ardupilot.org/plane/docs/common-iflight-blitzf7AIO.html#pinout).
I used SERIAL4 (T4 and R4 ports).
   Note: Make sure the coating of the enameled wire melts as you solder them for proper connection.
9. Connect the TX pin of the Raspberry Pi to the RX pin of the flight controller.
10. Connect the RX pin of the Raspberry Pi to the TX pin of the flight controller.



## Test Motors
Note: remove the propellers before testing the motors.

1. Connect to the flight controller using the QGC. And go to the Vehicle Configuration by clicking on the `Q` icon on the top left corner.
2. Go to the Motors tab.
3. Place the motors in the correct direction in front of you. M2 and M4 are the front motors. The white arrow printed on the flight controller board shows the front direction, in our setup it should be facing the table. Note that the motors are facing down in this setup.
    
4. Connect a battery to the flight controller.
5. Enable the slider and motor output then spin each motor slowly and feel the direction of rotation with your fingers.
6. If the motor is rotating in the wrong direction note its number.
7. Grab your solder and swap any two wires of the motor with wrong direction to reverse its rotation direction.
8. Finally, test one more time to make sure each motor rotates in the direction shown in the picture (M1 and M4 cw, M2 and M3 ccw).

## Configure the flight controller
After flashing the firmware and assembling the drone successfully, connect to the flight controller using USB and open QGC.
Set Alignment to None because in our design the flight controller arrow is facing forward.

### Frame
Choose Quad and `X` as the frame type.

### Sensor Calibration
Go to the `Sensors` tab and follow the calibration steps for Accelerometer, Level Horizon, and Gyro.

### UART Connection
1. Go to the `Parameters` tab.
2. Set `FRAME_TYPE` to BetaFlightX.
3. Set `ARMING_CHECK` to 0.
4. Set `SERIAL4_PROTOCOL` to MAVLink2 for Raspberry Pi serial connection.
5. Set `SERIAL4_BAUD` to 115200.
6. Set `SERIAL3_PROTOCOL` to MAVLink1 for the optical flow sensor.
7. Set `SERIAL3_BAUD` to 115200.
8. Set `SERIAL3_OPTIONS` to `Don’t forward mavlink to/from`.
9. Set `FLOW_TYPE` to Mavlink.
10. Set `RNGFND1_TYPE` to Mavlink.
11. Set `RNGFND1_MAX` to 200 to set range finder’s maximum range to 2m. 
12. Set `RNGFND1_MIN` to 1.
13. Set `RNGFND1_ORIENT` to 25 (Downward).
14. Click `Reboot Vehicle` from the `Tools` menu.

## Configure Raspberry Pi

### Install ubuntu
1. Download ubuntu server for Raspberry Pi from [here](https://ubuntu.com/download/raspberry-pi). I used 24.04.1 server arm64 raspi.
2. Use Raspberry Pi Imager to install the downloaded image on an SD card.
3. During the installation set up WLan, username and password, and enable ssh for easier access.
4. Insert the card into the Raspberry Pi and boot.

### Install ROS 2
1. Follow instructions [here](https://docs.ros.org/en/jazzy/Installation.html) to install ROS 2 Jazzy.
2. Add ros to bashrc: 
   ```
   echo "source /opt/ros/jazzy/setup.bash" >> ~/.bashrc
   source ~/.bashrc
   ```

### Install Mavros
See [here](https://github.com/mavlink/mavros/blob/ros2/mavros/README.md#binary-installation-deb) for instructions.
Note that you need to use the appropriate ros distribution foxy, jazzy, etc.

```
sudo apt install ros-jazzy-mavros ros-jazzy-mavros-extras
sudo apt install geographiclib-tools
sudo geographiclib-get-geoids egm96-5
sudo geographiclib-get-gravity egm96
sudo geographiclib-get-magnetic igrf
```

### UART Connection
1. add the following lines to the `/boot/firmware/config.txt`:
  ```
  enable_uart=1
  dtoverlay=disable-bt,uart0,ctsrts
  ```
1. Ensure there is no line like `console=serial0,115200` in `/boot/firmware/cmdline.txt`. If present, remove it to prevent the Raspberry Pi from using UART for console output.
2. Reboot Raspberry Pi: `sudo reboot`.
3. Power up the drone via a battery. And connect the Raspberry Pi's power cable to the flight controller board.

### Run Mavros
1. SSH to the Raspberry Pi.
2. Start `tmux`.
3. Split the window using `control+b` then `%`.
4. In one window run `ros2 launch mavros apm.launch fcu_url:=serial:///dev/ttyAMA0:115200 gcs_url:=udp://@192.168.8.130:14550`
5. In the other run `ros2 topic echo /mavros/state`

### Install Mavlink-Router
Install [mavlink-router](https://github.com/mavlink-router/mavlink-router?tab=readme-ov-file).
```mavlink-routerd -e 192.168.8.197:14550 /dev/ttyAMA0:57600```

### MavProxy
https://ardupilot.org/mavproxy/docs/getting_started/starting.html
```mavproxy.py --master=/dev/ttyAMA0 --baudrate=115200```

### Troubleshoot
- Ensure TX and RX pins are properly connected (use GPIO 14 for TX and GPIO 15 for RX).
- Use a multimeter or a simple circuit like an LED and a battery to test the connections of UART pins.
- Ensure `ls -l /dev/serial*` or `ls -l /dev/ttyAMA0` shows an entry.
- Ensure the baud rate is set correctly (115200 is typical).

### Useful Resources
https://ardupilot.github.io/MethodicConfigurator/
https://www.ecalc.ch/index.htm

### Notes
- Use 22 or 20 AWG wire for 5V 5A power inputs.
- Use 30 or 28 AWG wire for signal connections.

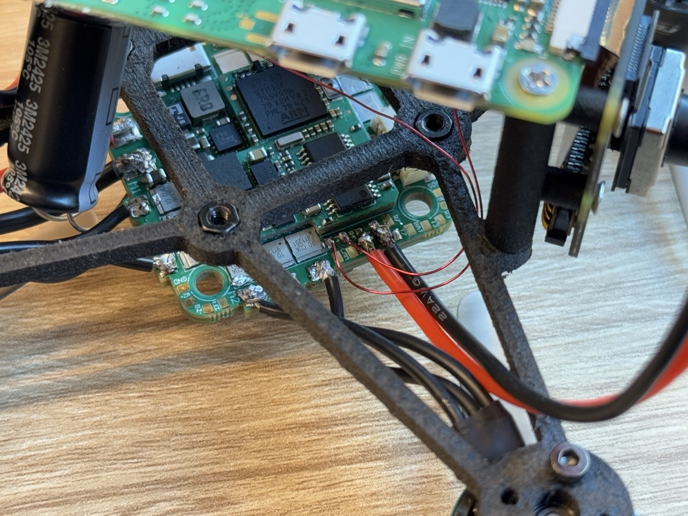
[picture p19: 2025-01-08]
images/fc_raspberry_connection.jpeg

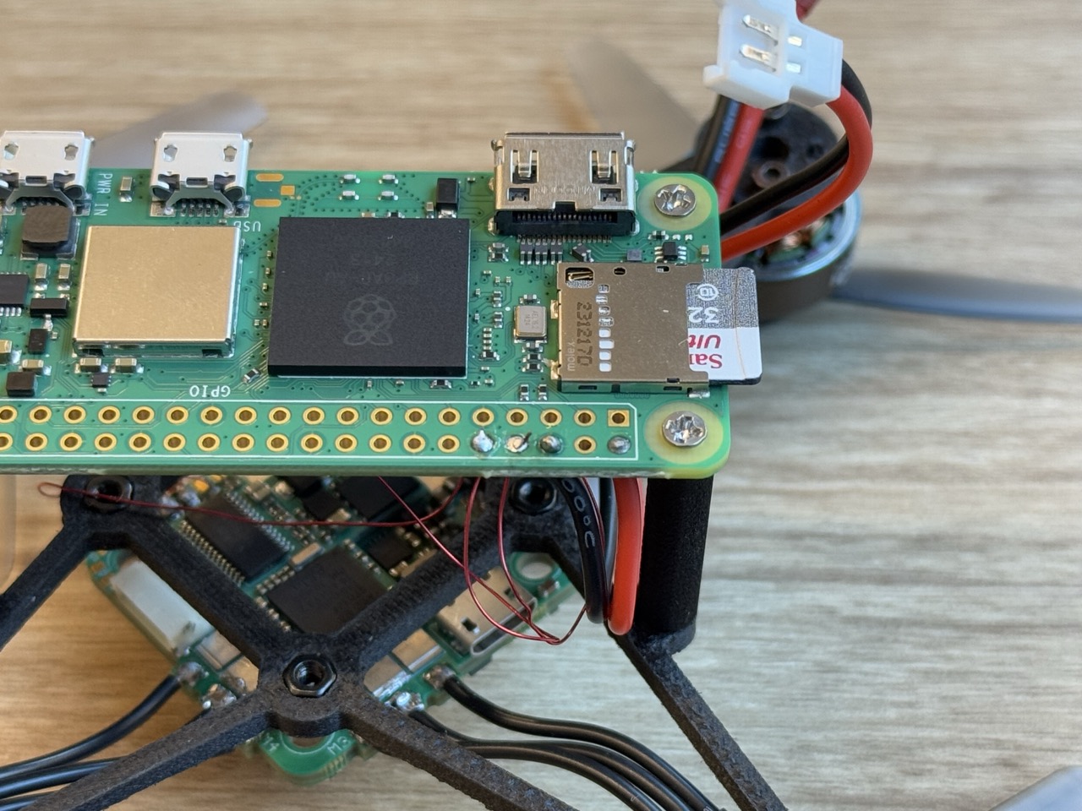
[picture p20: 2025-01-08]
images/raspberry_fc_connection.jpeg

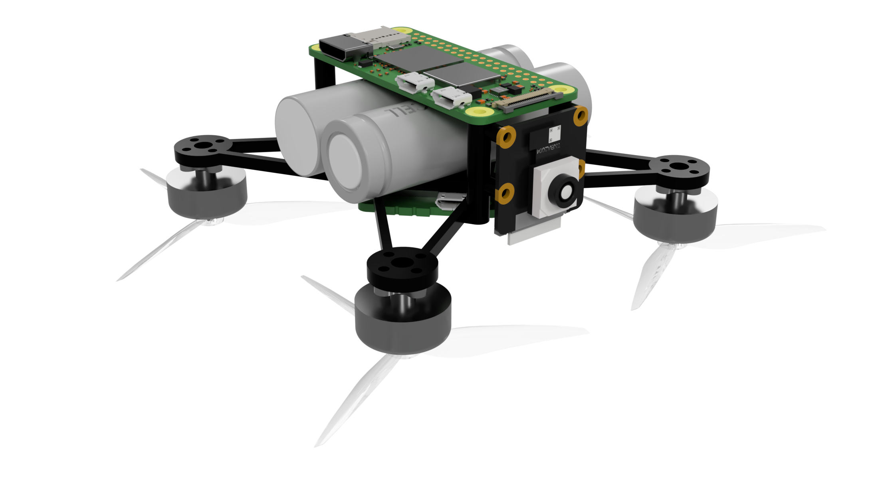
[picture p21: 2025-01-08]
images/drone_render.png

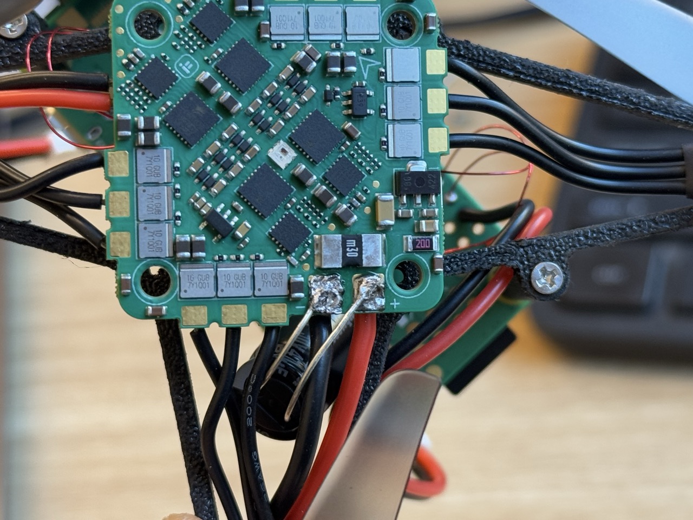
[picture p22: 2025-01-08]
images/capacitor.jpeg

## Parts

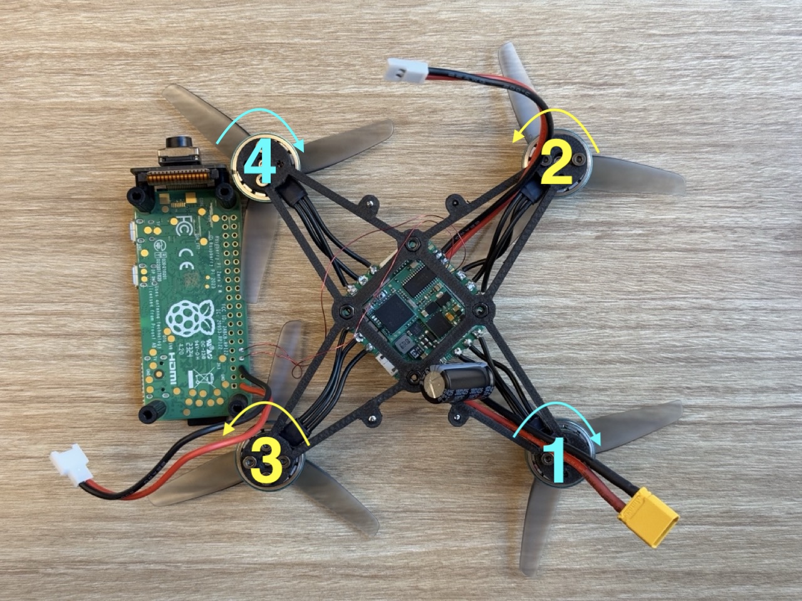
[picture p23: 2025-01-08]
images/parts_top_view.jpeg

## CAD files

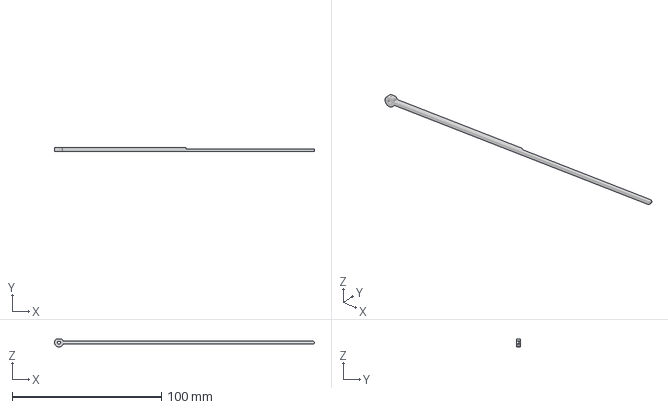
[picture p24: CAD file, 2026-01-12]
LightBenderv11/3d/rod_link_2_170mm.3mf
174.0 x 3.00 x 5.50 mm

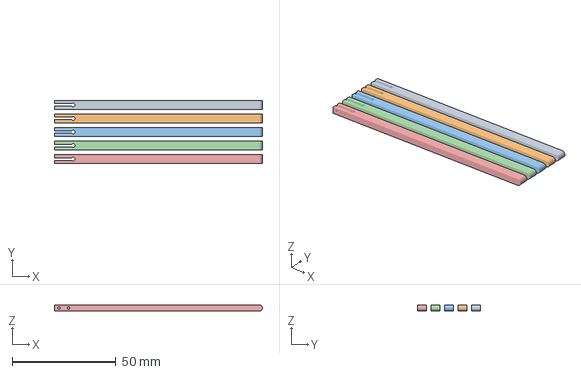
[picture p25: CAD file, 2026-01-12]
LightBenderv12/3d/rod.3mf
100.0 x 30.5 x 3.00 mm

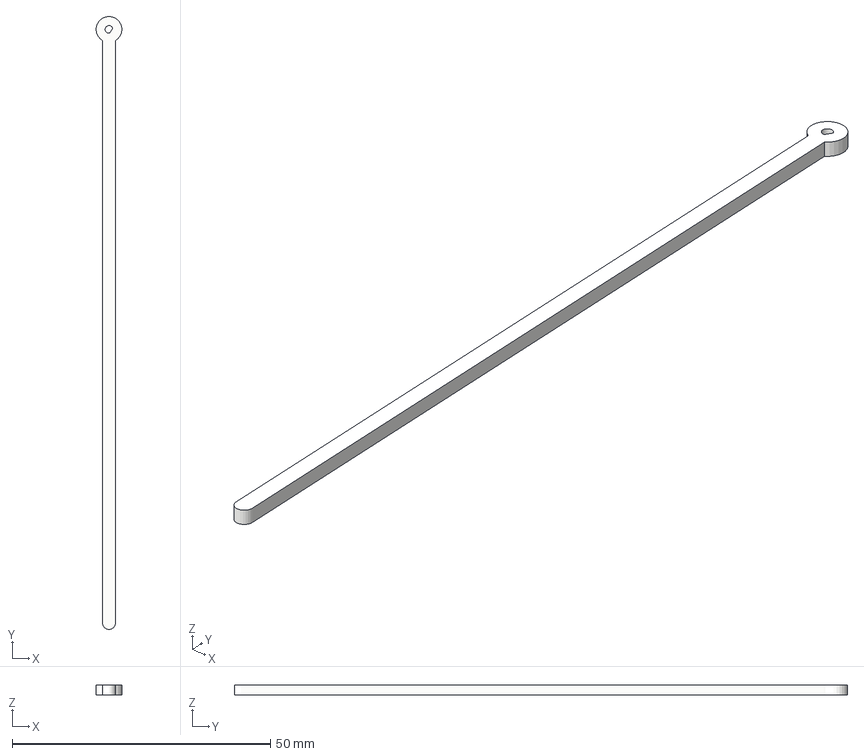
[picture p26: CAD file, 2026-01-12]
v10/3d/arm_rod.3mf
4.98 x 118.8 x 2.00 mm

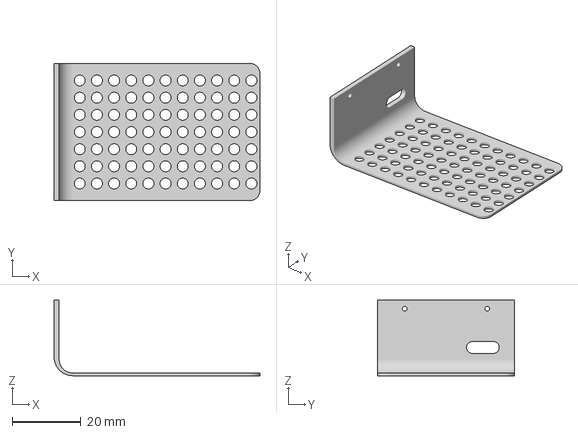
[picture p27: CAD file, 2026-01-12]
LightBenderv11/3d/rpi_cover.3mf
60.0 x 40.0 x 22.0 mm

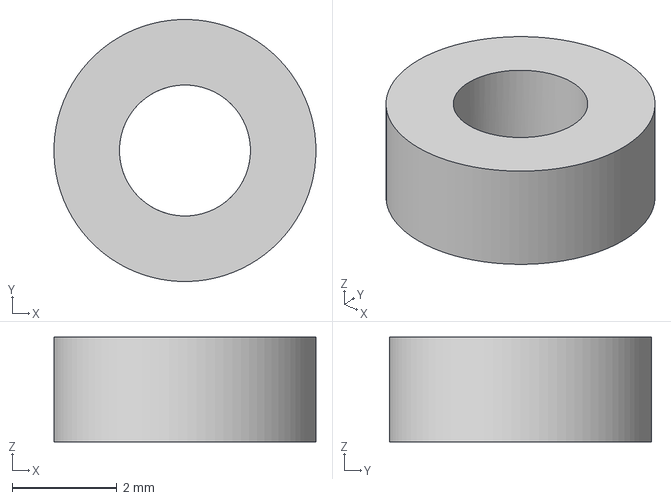
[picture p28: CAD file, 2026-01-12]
LightBenderv12/3d/spacer.3mf
5.00 x 5.00 x 2.00 mm

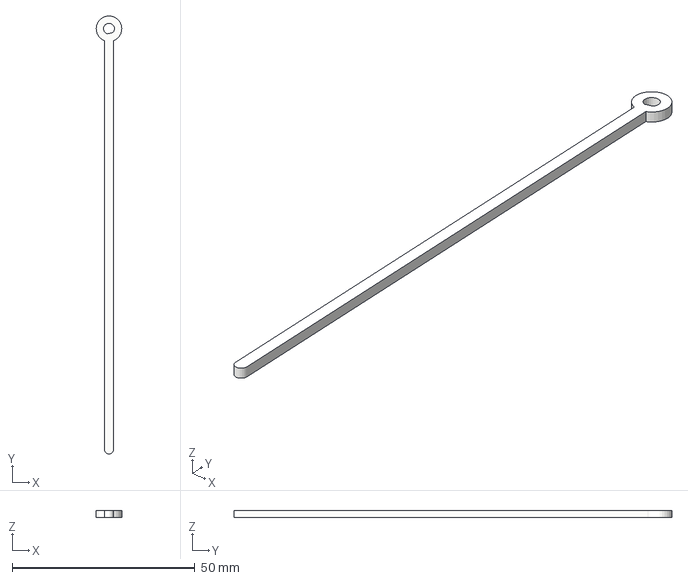
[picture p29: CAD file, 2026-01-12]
v10/3d/arm_tube.3mf
7.00 x 119.7 x 2.00 mm

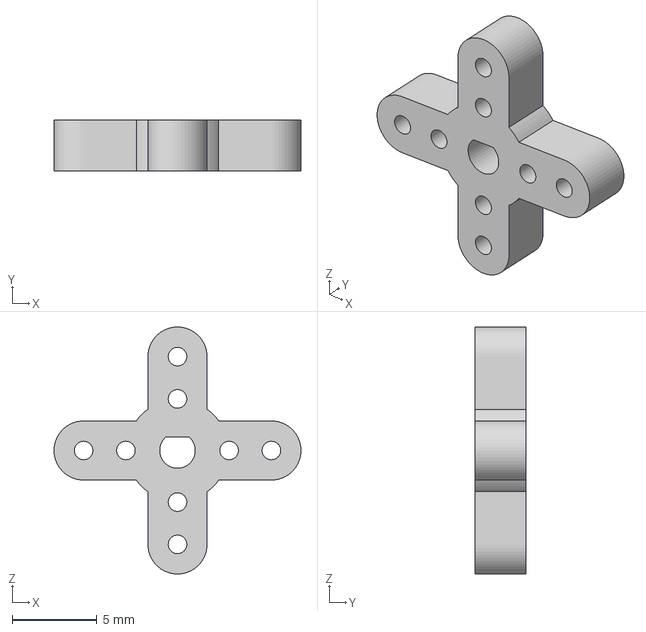
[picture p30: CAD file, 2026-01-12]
LightBenderv11/3d/rod_fin.3mf
14.6 x 3.00 x 14.6 mm

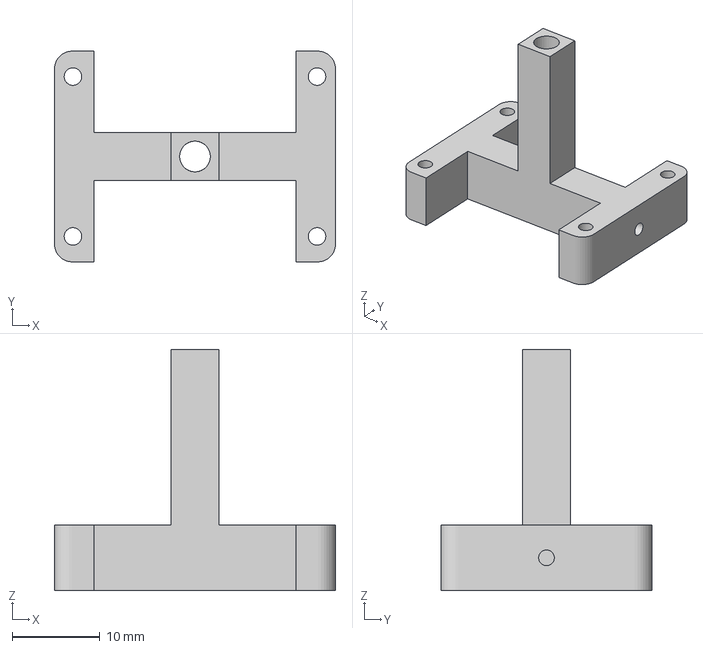
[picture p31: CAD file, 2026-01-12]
v10/3d/box_bottom.3mf
32.0 x 24.0 x 27.5 mm

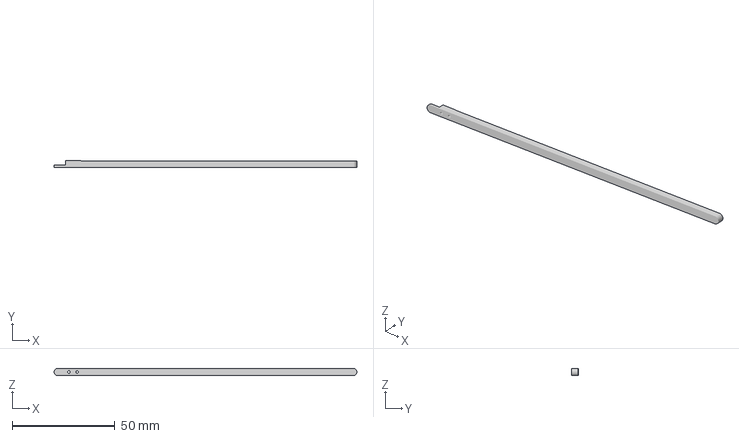
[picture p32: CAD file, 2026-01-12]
LightBenderv11/3d/tube_link_fin.3mf
147.5 x 3.20 x 3.50 mm

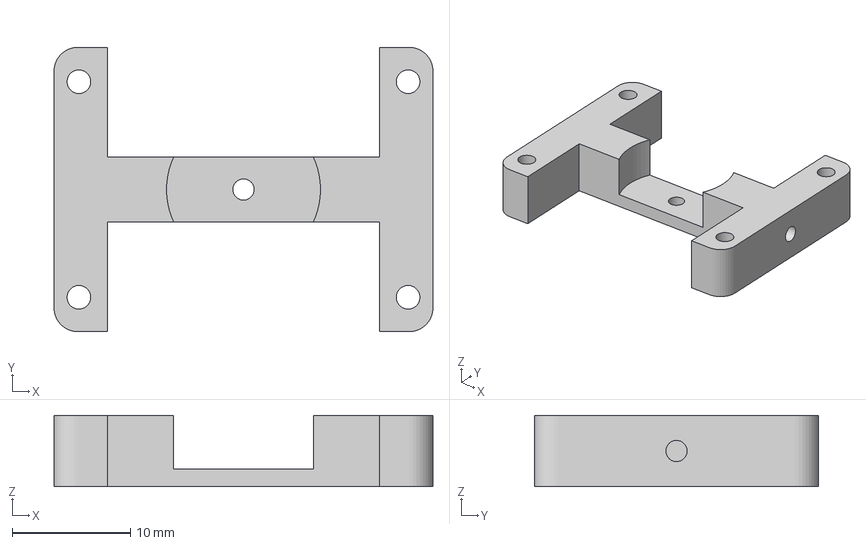
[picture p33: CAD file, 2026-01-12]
v10/3d/box_top.3mf
32.0 x 24.0 x 6.00 mm

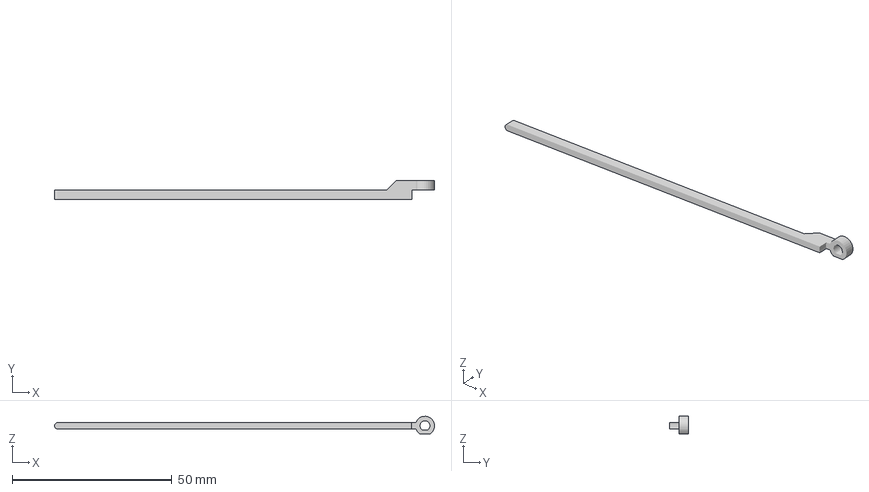
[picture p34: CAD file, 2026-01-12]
LightBenderv11/3d/tube_link_2_d.3mf
119.0 x 6.00 x 5.48 mm

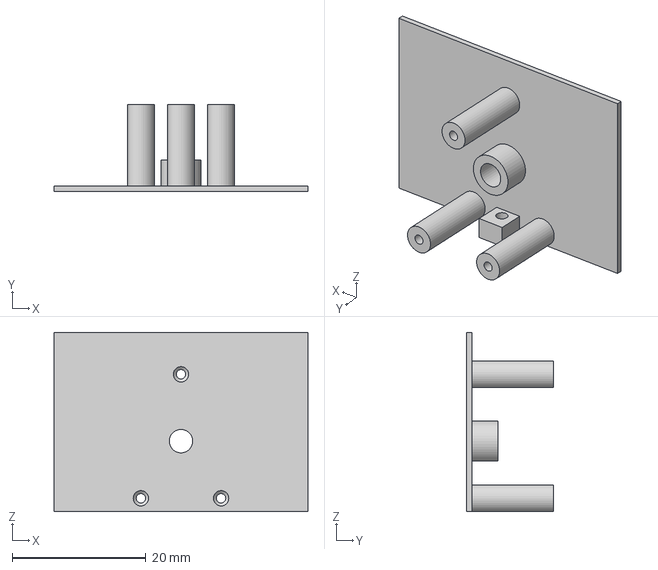
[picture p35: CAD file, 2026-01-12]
LightBenderv11/3d/shaft_holder_2.3mf
38.0 x 12.9 x 26.8 mm

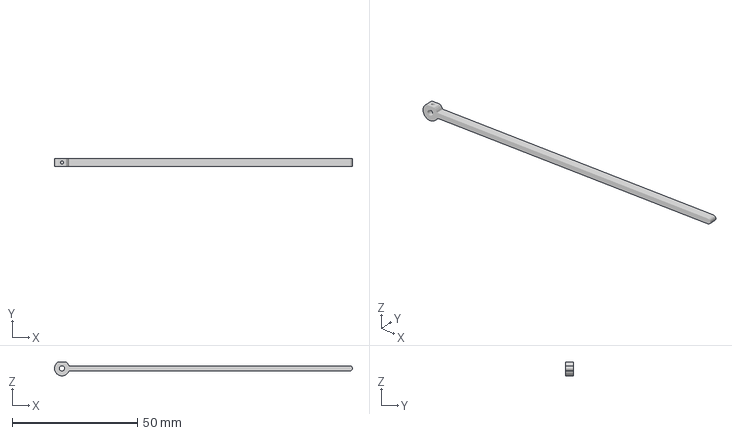
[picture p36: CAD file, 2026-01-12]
LightBenderv11/3d/rod_link.3mf
119.0 x 3.00 x 5.48 mm

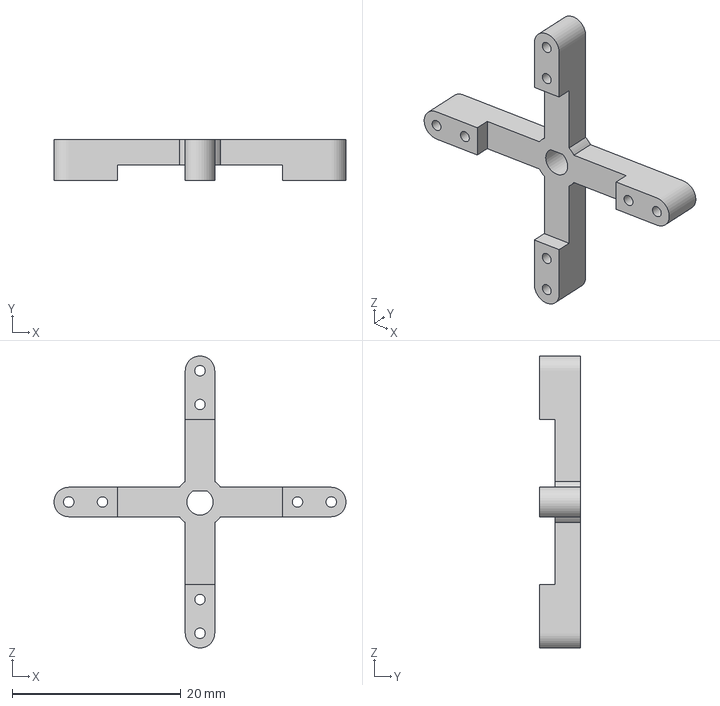
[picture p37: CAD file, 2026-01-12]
LightBenderv11/3d/tube_fin_2.3mf
34.6 x 4.80 x 34.6 mm

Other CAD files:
LightBenderv11/3d/tube_link_2.3mf
LightBenderv11/3d/rod_link_2x.3mf
LightBenderv11/3d/shaft_holder_2_nb-3002.3mf
LightBenderv11/3d/tube_fin.3mf
LightBenderv11/3d/rod_fin_2.3mf
LightBenderv11/3d/rod_fin_m1.2.3mf
LightBenderv11/3d/rod_link_d.3mf
LightBenderv11/3d/rof_link_fin.3mf
LightBenderv11/3d/servo_holder.3mf
LightBenderv11/3d/servo_holder_nb-3002.3mf
LightBenderv11/3d/shaft_holder.3mf
LightBenderv11/3d/tube_fin_m1.2.3mf
LightBenderv11/3d/tube_link.3mf
LightBenderv11/3d/tube_link_2_170mm.3mf
LightBenderv11/3d/tube_link_2x.3mf
v0/3d/camera_holder_l.3mf
v0/3d/camera_holder_r.3mf
v0/3d/frame.3mf
v0/3d/initial/ball_joint_mount/ball.3mf
v0/3d/initial/ball_joint_mount/bolt.3mf
v0/3d/initial/ball_joint_mount/frame_mount.3mf
v0/3d/initial/body_frame_picm5.3mf
v0/3d/initial/body_frame_picm5_v42.3mf
v0/3d/initial/body_frame_picm5_v45.3mf
v0/3d/initial/body_frame_v90.3mf
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

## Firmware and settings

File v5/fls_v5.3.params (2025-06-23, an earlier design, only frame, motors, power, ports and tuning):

1	1	ATC_ANGLE_BOOST	1	2
1	1	ATC_ANG_LIM_TC	1.000000000000000000	9
1	1	ATC_ANG_PIT_P	5.000000000000000000	9
1	1	ATC_ANG_RLL_P	5.000000000000000000	9
1	1	ATC_ANG_YAW_P	4.500000000000000000	9
1	1	ATC_RATE_FF_ENAB	1	2
1	1	ATC_RATE_P_MAX	0.000000000000000000	9
1	1	ATC_RATE_R_MAX	0.000000000000000000	9
1	1	ATC_RATE_Y_MAX	0.000000000000000000	9
1	1	ATC_RAT_PIT_D	0.001874999958090484	9
1	1	ATC_RAT_PIT_D_FF	0.000000000000000000	9
1	1	ATC_RAT_PIT_FF	0.000000000000000000	9
1	1	ATC_RAT_PIT_FLTD	40.000000000000000000	9
1	1	ATC_RAT_PIT_FLTE	0.000000000000000000	9
1	1	ATC_RAT_PIT_FLTT	40.000000000000000000	9
1	1	ATC_RAT_PIT_I	0.100000001490116119	9
1	1	ATC_RAT_PIT_IMAX	0.500000000000000000	9
1	1	ATC_RAT_PIT_NEF	0	2
1	1	ATC_RAT_PIT_NTF	0	2
1	1	ATC_RAT_PIT_P	0.125000000000000000	9
1	1	ATC_RAT_PIT_PDMX	0.000000000000000000	9
1	1	ATC_RAT_PIT_SMAX	0.000000000000000000	9
1	1	ATC_RAT_RLL_D	0.002499999944120646	9
1	1	ATC_RAT_RLL_D_FF	0.000000000000000000	9
1	1	ATC_RAT_RLL_FF	0.000000000000000000	9
1	1	ATC_RAT_RLL_FLTD	41.000000000000000000	9
1	1	ATC_RAT_RLL_FLTE	0.000000000000000000	9
1	1	ATC_RAT_RLL_FLTT	40.000000000000000000	9
1	1	ATC_RAT_RLL_I	0.135000005364418030	9
1	1	ATC_RAT_RLL_IMAX	0.500000000000000000	9
1	1	ATC_RAT_RLL_NEF	0	2
1	1	ATC_RAT_RLL_NTF	0	2
1	1	ATC_RAT_RLL_P	0.168750002980232239	9
1	1	ATC_RAT_RLL_PDMX	0.000000000000000000	9
1	1	ATC_RAT_RLL_SMAX	0.000000000000000000	9
1	1	ATC_RAT_YAW_D	0.000000000000000000	9
1	1	ATC_RAT_YAW_D_FF	0.000000000000000000	9
1	1	ATC_RAT_YAW_FF	0.000000000000000000	9
1	1	ATC_RAT_YAW_FLTD	0.000000000000000000	9
1	1	ATC_RAT_YAW_FLTE	2.000000000000000000	9
1	1	ATC_RAT_YAW_FLTT	81.000000000000000000	9
1	1	ATC_RAT_YAW_I	0.017999999225139618	9
1	1	ATC_RAT_YAW_IMAX	0.500000000000000000	9
1	1	ATC_RAT_YAW_NEF	0	2
1	1	ATC_RAT_YAW_NTF	0	2
1	1	ATC_RAT_YAW_P	0.150000005960464478	9
1	1	ATC_RAT_YAW_PDMX	0.000000000000000000	9
1	1	ATC_RAT_YAW_SMAX	0.000000000000000000	9
1	1	BATT2_MONITOR	0	2
1	1	BATT3_MONITOR	0	2
1	1	BATT4_MONITOR	0	2
1	1	BATT5_MONITOR	0	2
1	1	BATT6_MONITOR	0	2
1	1	BATT7_MONITOR	0	2
1	1	BATT8_MONITOR	0	2
1	1	BATT9_MONITOR	0	2
1	1	BATT_AMP_OFFSET	0.000000000000000000	9
1	1	BATT_AMP_PERVLT	40.200000762939453125	9
1	1	BATT_ARM_MAH	0	6
1	1	BATT_ARM_VOLT	7.500000000000000000	9
1	1	BATT_CAPACITY	650	6
1	1	BATT_CRT_MAH	0.000000000000000000	9
1	1	BATT_CRT_VOLT	7.199999809265136719	9
1	1	BATT_CURR_PIN	11	2
1	1	BATT_FS_CRT_ACT	5	2
1	1	BATT_FS_LOW_ACT	0	2
1	1	BATT_FS_VOLTSRC	0	2
1	1	BATT_LOW_MAH	0.000000000000000000	9
1	1	BATT_LOW_TIMER	10	2
1	1	BATT_LOW_VOLT	7.300000190734863281	9
1	1	BATT_MONITOR	4	2
1	1	BATT_OPTIONS	0	6
1	1	BATT_SERIAL_NUM	-1	6
1	1	BATT_VLT_OFFSET	0.000000000000000000	9
1	1	BATT_VOLT_MULT	21.100000381469726563	9
1	1	BATT_VOLT_PIN	10	2
1	1	FLTMODE1	0	2
1	1	FLTMODE2	0	2
1	1	FLTMODE3	0	2
1	1	FLTMODE4	0	2
1	1	FLTMODE5	0	2
1	1	FLTMODE6	0	2
1	1	FLTMODE_CH	5	2
1	1	FLTMODE_GCSBLOCK	0	6
1	1	FRAME_CLASS	1	2
1	1	FRAME_TYPE	1	2
1	1	INS_GYRO_FILTER	100	4
1	1	INS_HNTCH_ATT	40.000000000000000000	9
1	1	INS_HNTCH_BW	80.000000000000000000	9
1	1	INS_HNTCH_ENABLE	1	2
1	1	INS_HNTCH_FM_RAT	1.000000000000000000	9
1	1	INS_HNTCH_FREQ	400.000000000000000000	9
1	1	INS_HNTCH_HMNCS	3	6
1	1	INS_HNTCH_MODE	3	2
1	1	INS_HNTCH_OPTS	6	4
1	1	INS_HNTCH_REF	1.000000000000000000	9
1	1	MOT_BAT_CURR_MAX	0.000000000000000000	9
1	1	MOT_BAT_CURR_TC	5.000000000000000000	9
1	1	MOT_BAT_IDX	0	2
1	1	MOT_BAT_VOLT_MAX	8.399999618530273438	9
1	1	MOT_BAT_VOLT_MIN	6.599999904632568359	9
1	1	MOT_BOOST_SCALE	0.000000000000000000	9
1	1	MOT_HOVER_LEARN	2	2
1	1	MOT_OPTIONS	0	4
1	1	MOT_PWM_MAX	2000	4
1	1	MOT_PWM_MIN	1000	4
1	1	MOT_PWM_TYPE	5	2
1	1	MOT_SAFE_DISARM	0	2
1	1	MOT_SAFE_TIME	1.000000000000000000	9
1	1	MOT_SLEW_DN_TIME	0.000000000000000000	9
1	1	MOT_SLEW_UP_TIME	0.000000000000000000	9
1	1	MOT_SPIN_ARM	0.100000001490116119	9
1	1	MOT_SPIN_MAX	0.949999988079071045	9
1	1	MOT_SPIN_MIN	0.150000005960464478	9
1	1	MOT_SPOOL_TIME	0.100000001490116119	9
1	1	MOT_SPOOL_TIM_DN	0.000000000000000000	9
1	1	MOT_THST_EXPO	0.349999994039535522	9
1	1	MOT_THST_HOVER	0.199573636054992676	9
1	1	MOT_YAW_HEADROOM	200	4
1	1	SERIAL0_BAUD	115	6
1	1	SERIAL0_PROTOCOL	2	2
1	1	SERIAL1_BAUD	115	6
1	1	SERIAL1_OPTIONS	0	4
1	1	SERIAL1_PROTOCOL	2	2
1	1	SERIAL2_BAUD	115	6
1	1	SERIAL2_OPTIONS	0	4
1	1	SERIAL2_PROTOCOL	42	2
1	1	SERIAL3_BAUD	230	6
1	1	SERIAL3_OPTIONS	0	4
1	1	SERIAL3_PROTOCOL	5	2
1	1	SERIAL4_BAUD	115	6
1	1	SERIAL4_OPTIONS	1024	4
1	1	SERIAL4_PROTOCOL	1	2
1	1	SERIAL5_BAUD	57	6
1	1	SERIAL5_OPTIONS	0	4
1	1	SERIAL5_PROTOCOL	-1	2
1	1	SERIAL6_BAUD	57	6
1	1	SERIAL6_OPTIONS	0	4
1	1	SERIAL6_PROTOCOL	23	2
1	1	SERIAL7_BAUD	115	6
1	1	SERIAL7_OPTIONS	0	4
1	1	SERIAL7_PROTOCOL	16	2
1	1	SERIAL8_BAUD	115	6
1	1	SERIAL8_OPTIONS	0	4
1	1	SERIAL8_PROTOCOL	2	2
1	1	SERVO1_FUNCTION	33	4
1	1	SERVO1_MAX	2000	4
1	1	SERVO1_MIN	1000	4
1	1	SERVO1_REVERSED	0	2
1	1	SERVO1_TRIM	1000	4
1	1	SERVO2_FUNCTION	34	4
1	1	SERVO2_MAX	2000	4
1	1	SERVO2_MIN	1000	4
1	1	SERVO2_REVERSED	0	2
1	1	SERVO2_TRIM	1000	4
1	1	SERVO3_FUNCTION	35	4
1	1	SERVO3_MAX	2000	4
1	1	SERVO3_MIN	1000	4
1	1	SERVO3_REVERSED	0	2
1	1	SERVO3_TRIM	1000	4
1	1	SERVO4_FUNCTION	36	4
1	1	SERVO4_MAX	2000	4
1	1	SERVO4_MIN	1000	4
1	1	SERVO4_REVERSED	0	2
1	1	SERVO4_TRIM	1000	4
1	1	SERVO5_FUNCTION	0	4
1	1	SERVO5_MAX	1900	4
1	1	SERVO5_MIN	1100	4
1	1	SERVO5_REVERSED	0	2
1	1	SERVO5_TRIM	1500	4
1	1	SERVO6_FUNCTION	0	4
1	1	SERVO6_MAX	1900	4
1	1	SERVO6_MIN	1100	4
1	1	SERVO6_REVERSED	0	2
1	1	SERVO6_TRIM	1500	4
1	1	SERVO7_FUNCTION	0	4
1	1	SERVO7_MAX	1900	4
1	1	SERVO7_MIN	1100	4
1	1	SERVO7_REVERSED	0	2
1	1	SERVO7_TRIM	1500	4
1	1	SERVO8_FUNCTION	0	4
1	1	SERVO8_MAX	1900	4
1	1	SERVO8_MIN	1100	4
1	1	SERVO8_REVERSED	0	2
1	1	SERVO8_TRIM	1500	4
1	1	SERVO9_FUNCTION	0	4
1	1	SERVO9_MAX	1900	4
1	1	SERVO9_MIN	1100	4
1	1	SERVO9_REVERSED	0	2
1	1	SERVO9_TRIM	1500	4

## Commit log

2025-01-08 add 3d models, flight controler, and build instructions
    [body_frame_v90.3mf, camera_mount_a_23mm.3mf, camera_mount_b_23mm.3mf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]
2025-01-21 add ball joint models
    [ball.3mf, bolt.3mf, frame_mount.3mf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]
2025-04-21 Add assembly guides
2025-04-21 Add assembly images
    [frame_v3.3mf]
2025-04-22 Refine frame and landing gear design
    [landing_gear_v2.3mf]
2025-04-23 Add flow sensor, compass, and offboard control
2025-04-25 Update 3d designs
    [frame_v4.3mf, landing_gear_v3.3mf, pi_holder_v2_a.3mf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]
2025-04-25 Update pid gains
2025-06-06 Update models and readme
    [cam_holder_l.3mf, cam_holder_r.3mf, frame_v5_3x6.6.3mf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]
2025-06-23 Add params
    [fls_v5.3.params]
2025-07-06 Refactor motion planner
    [filter_holder.3mf, frame.3mf, landing_gear.3mf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]
2025-07-06 Refactor v0
    [ball.3mf, body_frame_picm5.3mf, body_frame_picm5_v42.3mf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]
2025-07-18 Update filter instructions
2026-01-12 add assets
    [Body171.3mf, Body172.3mf, arm_rod.3mf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]
